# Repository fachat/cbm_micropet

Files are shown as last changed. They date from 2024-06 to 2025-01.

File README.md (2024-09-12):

# Micro-PET R3

Note: this is a part of a larger set of repositories, with [upet_family](https://github.com/fachat/upet_family) as the main repository.

This is a re-incarnation of the Commodore PET computer(s) from the later 1970s.

It is build on a PCB slightly larger than a Eurocard board and has only parts that can still be obtained new in 2024.
The current version is 3.0A

Picture of a MicroPET

Here is the [Overview video](https://youtu.be/COlfqcaY7rI)

Some more videos on the build process can be found here [YT 8-bit times](https://youtube.com/playlist?list=PLi1dzy7kw1iybjcUccgjCV4fhNH4IPWSx)

## Features

The board is built with a number of features:

- Commodore 3032 / 4032 / 8032 / 8296 with options menu to select at boot
  - Boot-menu to select different PET versions to run (BASIC 1, 2, 4)
  - 40 and 80 col character display
  - 8296 memory map emulation
  - IEEE488 interface (card edge and 24pin flat ribbon cable)
  - Tape connector (card edge, 5V only)
  - PET graphics keyboard, or alternatively a C64 keyboard
- Improved system design:
  - 512k video RAM, plus 512k fast RAM, accessible using banks on the W65816 CPU
  - boot from an SPI Flash ROM
  - up to 17.5 MHz mode (via configuration register)
  - Write protection for the PET ROMs once copied to RAM
  - lower 32k RAM mappable from all of the 512k fast RAM
  - Audio output using a DAC with DMA
- Improved Video output:
  - VGA colour video output
  - up to 96x72 characters on screen
  - hires modes up to a 768x576 resolution
  - 16 out of 64 colour palette, Colour-PET or C128 VDC-compatible, Sprites
  - Hires graphics mode (using a configuration register)
  - modifyable character set
  - multiple video pages mappable to $8000 video mem address

## Overview

The system architecture is actually rather simple, as you can see in the following graphics.

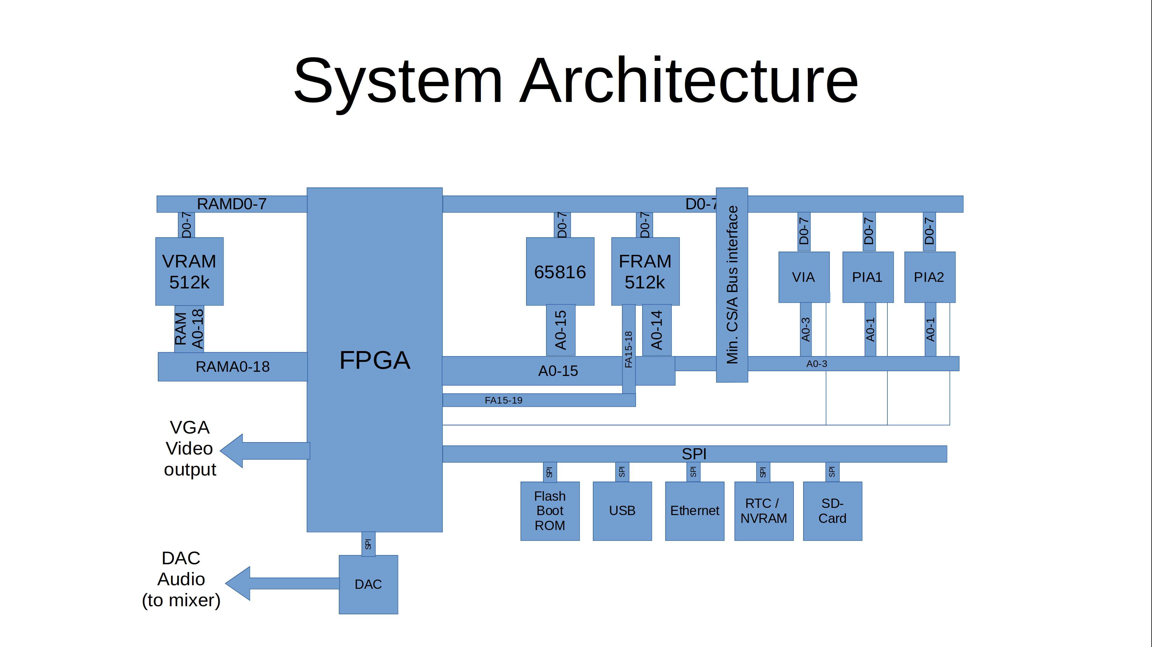
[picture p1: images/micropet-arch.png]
MicroPET System Architecture


The main functionality is "hidden" inside the FPGA. It does:

1. clock generation and management
2. memory mapping
3. video generation.
4. SPI interface and boot
5. DAC DMA

On the CPU side of the FPGA it is actually a rather almost normal 65816 computer, 
with the exception that the bank register (that catches and stores the address lines 
A16-23 from the CPU's data bus) is in the FPGA, and that there is no ROM. The ROM has been
replaced with some code in the FPGA that copies the initial program to the CPU accessible
RAM, taking it from the Flash Boot ROM via SPI. This actually simplifies the design,
as 

1. parallel ROMs are getting harder to come by and
2. they are typically not as fast as is needed, and
3. with the SPI boot they don't occupy valuable CPU address space.

The video generation is done using time-sharing access to the video RAM.
The VGA output is 768x576 at 60Hz. So there is a 28ns slot per pixel on the screen, 
with a pixel clock of 35MHz.

The system runs at 17.5MHz, so a byte of pixel output (i.e. eight pixels) has four
memory accesses to VRAM. Two of them are reserved for video access, one for fetching the
character data (e.g. at $08xxx in the PET), and the second one to fetch the "character ROM"
data, i.e. the pixel data for a character. This is also stored in VRAM, and is being loaded
there from the Flash Boot ROM by the initial boot loader.

The FPGA reads the character data, stores it to fetch the character pixel data, and streams
that out using its internal video shift register.

For more detailled descriptions of the features and how to use them, pls see the 
[FPGA repository](https://github.com/fachat/upet_fpga) that contains the code for the FPGA,
as described in the next section.

## Version History

- [Revision 2.1A](https://github.com/fachat/cbm_micropet/tree/r2.1a): the first one with boot-from-SPI, and card edge connectors for IEEE and tape.
- [Revision 1.1B](https://github.com/fachat/cbm_micropet/tree/r1.1b): the original one with parallel ROMs, and no SPI boot; also, no card edge connectors

## Building

Here are four subdirectories:

- [Board](Board/) that contains the board schematics and layout
- [Case](Case/) 3-D printed supports and keyboards to mount board in a C64c case

In addition, two other repositories are needed - they are separate as they are shared with other variants of the upet-family:

- [FPGA](https://github.com/fachat/upet_fpga) contains the VHDL code to program the FPGA logic chip used, and describes the configuration options - including the SPI usage, the DAC usage, and the Video features.
- [ROM](https://github.com/fachat/upet_roms) ROM contents to boot

### Board

To have the board built, you can use the gerbers that are stored in the zip file in the Board/production subdirectory.

To populate the board, there is an interactive bom (bill of materials) from KiCad, as well as the KiCad BOM CSV export in the [bom](Board/bom/) folder.
The parts I used are in the [Mouser BOM](Board/micropet_v3.0a-BOM.xlsx).

The BOM contains an Ethernet breakout board that is put into the connectors "above" the USB port. As an alternative you could use the 
[Wifi breakout board](https://github.com/fachat/upet_wifi). Note that at this time, this is not tested / programmed yet.

### FPGA

The FPGA is a Xilinx Spartan 6 programmable logic chip. It runs on 3.3V and it is programmed in VHDL.

To build the FPGA content, clone the [FPGA](https://github.com/fachat/upet_fpga) repository, and look for the ShellUPet.bin.
This needs to be programmed into the SPI flash chip containing the configration for the FPGA.

### ROM

To build the boot ROM image, clone the [ROM](https://github.com/fachat/upet_roms) repository, and build the spiimg70m file. This needs to be 
programmed into the SPI flash ROM containing the 65816 boot code.

The ROM image can be built using gcc, xa65, and make. Use your favourite EPROM programmer to burn it into the SPI Flash chip.

The ROM contains images of all required ROM images for BASIC 1, 2, and 4, and corresponding editor ROMs, including
some that have been extended with wedges.

The updated editor ROMs are from [Steve's Editor ROM project](http://www.6502.org/users/sjgray/projects/editrom/index.html) and can handle C64 keyboards, has a DOS wedge included, and resets into the Micro-PET boot menu.
For more details see the description in the ROM repository.

### Case

The [Case](Case/) subdirectory holds some supporting 3D models, to use an existing C64-II case for the Micro-PET. 

Also, it contains the models for custom key caps for a PET N-type keyboard, as is default for the Micro-PET. 
As keyboard PCB I suggest using Steve Gray's [PET keyboard replacements](http://cbmsteve.ca/mxkeyboards/index.html) using modern, MX-type key switches.

## Gallery (Still R2)

Picture of a MicroPET

Note: the published schematics and board has the extra wires fixed/included.

MicroPET with self-printed key caps

MicroPET running the 8296 burnin

MicroPET before adjusting a C64 case

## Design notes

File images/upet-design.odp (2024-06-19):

## System Architecture

A0-3

A0-1

A0-1

FA15-18

A0-15

D0-7

D0-7

D0-7

D0-7

SPI

SPI

SPI

SPI

SPI

SPI

D0-7

RAM
A0-18

D0-7

A0-14

Min. CS/A Bus interface

RAMD0-7

FPGA

D0-7

VRAM

512k

65816

FRAM

512k

VIA

PIA1

PIA2

RAMA0-18

VGA

Video

output

DAC

Audio

(to mixer)

A0-15

FA15-19

A0-3

SPI

Flash
Boot
ROM

USB

Ethernet

RTC /
NVRAM

SD-
Card

DAC

## Memory Map (boot)

ipl

ipl

CPU address space (lower 1M)

64k
bank0

Banks 0 … 7

Banks 8 … 15

64k
bank0

64k 8296

Ext. bank

Banks 2 … 7

64k video
bank

Banks 9 … 15

512k FRAM

Physical address space

The CPLD can only write (the IPL code from Flash) to VRAM, so the initial

Mapping maps VRAM to banks 0-7 of the CPU

512k VRAM

## Memory Map

CPU address space (lower 1M)

0-32k

32-
64k

Banks 1 … 15

Any of 16

32k blocks

In FRAM

4k
V

Bank 0, or

8296 mem expansion

In bank 1

Any of four 2k positions in video bank

8k
Chr

rom

8k
Chr

64k
bank0

64k 8296

Ext. bank

Banks 2 … 7

64k video
bank

Banks 9 … 15

512k FRAM

Physical address space

512k VRAM

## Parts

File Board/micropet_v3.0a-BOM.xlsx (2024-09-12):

Designator | Footprint | Quantity | Orig | Value | MOUSER | MPN | Alternate
BEEP1 | JP2 | 1 |  | PIEZOBEEPER | 253-AE2038E4WA | AE-2038E-4WA |  | (To be put on cable to JP2)
C1, C12, C13, C14, C15, C16, C17, C18, C19, C2, C20, C21, C22, C23, C24, C25, C27, C3, C31, C32, C33, C34, C35, C4, C41, C42, C43, C44, C45, C46, C47, C48, C53, C54, C55, C56, C57, C58, C59, C60, C61, C62, C63, C64, C67, C68, C69, C70, C71 | C0603 | 49 |  | 0.1u | 710-885012206020 | 885012206020
C10, C11 | C0603 | 2 |  | 1u | 710-885012206020 | 885012206020
C26 | E2,5-6 | 1 |  | 47u | 710-860010372004 | 860010372004
C28, C36, C37, C38 | E2,5-6 | 4 |  | 22u | 710-860010372002 | 860010372002
C29, C30, C39, C40 | C0603 | 4 |  | 18p | 80-C0603C180K4HACTU | C0603C180K4HACTU |  |  | 77-VJ0603A180JXQCBC | VJ0603A180JXQCW1BC
C49, C50, C51, C52 | C050-025X075 | 4 |  | 1u | 710-860020672005 | 860020672005
C5 | E5-8,5 | 1 |  | 47u | 710-860010372004 | 860010372004
C6 | E5-6 | 1 |  | 47u | 710-860010372004 | 860010372004
C65, C66 | C0805 | 2 |  | 22u | 187-CL21A226MPQNNNE | CL21A226MPQNNNE
C7, C8 | C0603 | 2 |  | 100n | 710-885012206020 | 885012206020
C9 | C0603 | 1 |  | 1.0u Cer | 710-885012206020 | 885012206020
D1, D5, D6, D8 | D-5 | 4 |  | 1N4148 | 78-1N4148 | 1N4148TR |  |  | 512-1N4148 | 1N4148
D10, D11, D2, D3, D4, D9 | DO35-7 | 6 |  | 1N4148DO35-7 | 78-1N4148 | 1N4148TR |  |  | 512-1N4148 | 1N4148
H1, H2, H3, H4, H5, H6, H7 | 3.2 |  | 7 | MOUNT-HOLE3.2
IC1, IC13 | SOP32 | 2 |  | RAMSOCK32TO512KSOP | 870-61C5128AS-25QLI | IS61C5128AS-25QLI
IC10, IC11 | PLCC44 | 2 |  | PIAPLCC | 955-W65C21N6TPLG-14 | W65C21N6TPLG-14
IC16 | SO24L | 1 |  | 74LVC8T245SO24 | 595-SN74LVC4245ADW | SN74LVC4245ADW |  |  | 595-74LVC8T245DWRG4 | SN74LVC8T245DWRG4
IC2 | SO20W | 1 |  | 74245DW | 595-SN74HCT245DWR | SN74HCT245DWR
IC3 | SO14 | 1 |  | 7400D | 595-SN74HCT00DR | SN74HCT00DR
IC4 | SO14 | 1 |  | 7486D | 771-74HCT86D-T | 74HCT86D,653
IC5 | DIL16 | 1 |  | 74145N | 595-SN74LS145N | SN74LS145N | 595-SN74LS145NE4 | SN74LS145NE4
IC6 | SO14 | 1 |  | 74125D | 595-SN74LVC125AD | SN74LVC125AD
IC7 | SO16 | 1 |  | 74138D | 771-74LVC138AD-T | 74LVC138AD,118
IC8 | TQFP32-5MM | 1 |  | MAX3421E | 700-MAX3421EEHJT | MAX3421EEHJ+T
IC9 | PLCC44 | 1 |  | VIAPLCC | 955-W65C22N6TPLG-14 | W65C22N6TPLG-14
 | PLCC44 Socket | 4 |  |  | 517-8444-11B1-RK-TP | 8444-11B1-RK-TP
 | DIL16 Socket | 1 |  |  | 571-1-2199298-4 | 1-2199298-4
 | DIL20 Socket | 2 |  |  | 571-1-2199298-6 | 1-2199298-6
 | DIL08 Socket | 2 |  |  | 571-1-2199298-2 | 1-2199298-2
J1 | DCJ0202 | 1 |  | DCJ0202 | 806-KLDX-0202-A | KLDX-0202-A
JP1, JP10, JP6 | JP2 |  | 3 | JP2E
JP2, JP3, JP4, JP5, JP8, JP9 | JP1 |  | 6 | JP1E
JP7 | JP4 |  | 1 | JP4E
P6 | JP6 |  | 1 | CBMTAPE
P1 | C64KEYB |  | 1 | C64KEYB
P7 | C64KEYB |  | 1 | PETKEYBD
U$11 | JP6 |  | 1 | PETSKEY_EXTRA
U$8 | PinHeader_1x07_P2.54mm_Vertical |  | 1 | JP7
 |  | 3 |  | pin strip straight 20 pin | 649-1012937892001BLF | 10129378-920001BLF
JS1 | RENJS6 | 1 |  | RENOSCXLH | 972-XLH536070000000I | XLH536070.000000I
U$7 | FLAT10BOX | 1 |  | XILINXPROG | 710-61201021621 | 61201021621
LED1 | LED3MM | 1 |  | LED3MM | 696-SSL-LX305F4GD | SSL-LX305F4GD
P2 | FLAT24 | 1 |  | IEEE488FLATCABLE | 710-61202421621 | 61202421621
P3 | FLAT24 | 1 |  | PETUSERPORT | 710-61202421621 | 61202421621
Q1 | MICRO3 | 1 |  | IRLML5203 | 942-IRLML5203TRPBF | IRLML5203TRPBF
Q2 | TC26H | 1 |  | 32kHz | 710-830002995B | 830002995B
Q3 | HC49_S | 1 |  | 12MHz | 549-CYS6Q31C-12MHZ | CYS6Q31C-12.000MHZ
R20, R21, R6 | 0207_2V | 3 |  | 10 | 603-MF0207FTE26-10R | MF0207FTE26-10R
R1, R2, R4 | 0204_7 | 3 |  | 33 | 660-MF1/4LCT52R330J | MF1/4LCT52R330J
R7, R8 | 0204V | 2 |  | 68 | 660-MF1/4LCT52R680G | MF1/4LCT52R680G
R18, R31 | 0204V | 2 |  | 100 | 603-MFR-12FTF52-100R | MFR-12FTF52-100R
R29 | 0207_2V | 1 |  | 330 | 603-MFR-12FTF52-330R | MFR-12FTF52-330R
R17, R22 | 0207_2V | 2 |  | 390 | 756-MFR3-390RFC | MFR3-390RFC |  |  | 603-MFR-25FBF52-390R | MFR-25FBF52-390R
R13, R14, R15 | 0204V | 3 |  | 470 | 708-RNF14FTD470R | RNF14FTD470R
R30, R32 | 0204V | 2 |  | 680 | 603-MFR-12FTF52-680R | MFR-12FTF52-680R
R26, R27, R28 | 0204V | 3 |  | 1k | 603-MFR-12FTF52-1K | MFR-12FTF52-1K
R5 | 0204_5 | 1 |  | 2k2 | 603-MFR-12FTF52-2K2 | MFR-12FTF52-2K2
R3 | 0207_2V | 1 |  | 2k4 | 71-CCF072K40JKE36 | CCF072K40JKE36
R23 | 0204_5 | 1 |  | 3k3 | 603-MFR-12FTF52-3K3 | MFR-12FTF52-3K3
R25 | 0207_2V | 1 |  | 4k7 | 603-MFR-12FTF52-3K3 | MFR-12FTF52-4K7
R10, R11, R24, R9 | 0207_2V | 4 |  | 10k | 756-MFR3-10KFC | MFR3-10KFC
R16 | 0207_2V | 1 |  | 100k | 756-MFR3-100KFC | MFR3-100KFC
RN1 | RN-9 | 1 |  | 10k | 652-4609X-1LF-10K | 4609X-101-103LF
RN2, RN4 | RN-9 | 2 |  | 2k4 | 652-4609X-1LF-2.2K | 4609X-101-222LF
RN3, RN5 | RN-9 | 2 |  | 5k1 | 652-4609X-101-512LF | 4609X-101-512LF
S1 | B3F-31XX | 1 |  | 31-XX | 653-B3F-3122 | B3F-3122
SN1 | SOIC8 | 1 |  | MCP48X2 | 579-MCP4802-E/SN | MCP4802-E/SN
U$1 | PLCC44 | 1 |  | W65C816SPLCC | 955-W65C816S6PLG-14 | W65C816S6PLG-14
U$12 | GRAVITECH-SDCARD | 1 |  | SD-CARD-GRAVI | 992-MICROSD-ADP | MICROSD-ADP
 |  | 1 |  | Socket | 200-BCS108LSTE | BCS-108-L-S-TE
U$13 | MSOP10 | 1 |  | MCP79510 | 579-MCP79510-I/MS | MCP79510-I/MS
U$14, U$4 | DIL08 | 2 |  | SPIFLASH | 804-25VF080B5CPAE | SST25VF080B-50-4C-PAE |  |  | Other 4M/8M SPI Flash chips may work, mileage may vary (this Spartan6 req. > 2.7M)
U$16 | PSOP-8-FIXED | 1 |  | AP2132BB | 621-AP2132BMP1.2TRG1 | AP2132BMP-1.2TRG1
U$2 | TQFP144 | 1 |  | XC6SLX9-TQG144 | 217-XC6SLX9-2TQG144C | XC6SLX9-2TQG144C
U$3 | TO92 | 1 |  | DS1813 | 700-DS1818-10T&R | DS1818-10+T&R
U$5, U$6 | DIL20 | 2 |  | 74LS641 | 595-SN74LS641-1N | SN74LS641-1N
U$9 | ETHOLIENC | 1 |  | ETHOLIENC | 909-ENC28J60-H | ENC28J60-H
 |  | 2 |  |  | 200-BCS105LSTE | BCS-105-L-S-TE
U1 | SOT-223-3_TabPin2 | 1 |  | AMS1117-3.3 | 637-LDI1117-3.3H | LDI1117-3.3H
U2 | SOT-23-5 | 1 |  | 74LVC1G04 | 595-SN74LVC1G04DBVR | SN74LVC1G04DBVR
USB1 | USB-A-H | 1 |  | USB-A-H | 710-614004190021 | 614004190021
X1 | 1503_09 | 1 |  | 1503_09 | 490-SJ1-3513N | SJ1-3513N |  |  | Jack connectors according to JISC 6560, 3.5 mm
X2 | HDR15RA | 1 |  | D-SUB15-HDR15RA | 523-7HDE15SD1CH4FVGA | L77HDE15SD1CH4FVGA
CN3 | MA156_6-2_KEYED |  | 1 | PORT_CASSETTE_EDGE
CN4 | MA156_12-2_IEEE |  | 1 | PORT_IEEE_EDGE

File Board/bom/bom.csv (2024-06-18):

Designator | Footprint | Quantity | Value | LCSC Part #
BEEP1 | JP2 | 1 | PIEZOBEEPER
C1, C12, C13, C14, C15, C16, C17, C18, C19, C2, C20, C21, C22, C23, C24, C25, C27, C3, C31, C32, C33, C34, C35, C4, C41, C42, C43, C44, C45, C46, C47, C48, C53, C54, C55, C56, C57, C58, C59, C60, C61, C62, C63, C64, C67, C68, C69, C70, C71 | C0603 | 49 | 0.1u
C10, C11 | C0603 | 2 | 1u
C26 | E2,5-6 | 1 | 47u
C28, C36, C37, C38 | E2,5-6 | 4 | 22u
C29, C30, C39, C40 | C0603 | 4 | 18p
C49, C50, C51, C52 | C050-025X075 | 4 | 1u
C5 | E5-8,5 | 1 | 47u
C6 | E5-6 | 1 | 47u
C65, C66 | C0805 | 2 | 22u
C7, C8 | C0603 | 2 | 100n
C9 | C0603 | 1 | 1.0u Cer
CN3 | MA156_6-2_KEYED | 1 | PORT_CASSETTE_EDGE
CN4 | MA156_12-2_IEEE | 1 | PORT_IEEE_EDGE
D1, D5, D6, D8 | D-5 | 4 | 1N4148
D10, D11, D2, D3, D4, D9 | DO35-7 | 6 | 1N4148DO35-7
H1, H2, H3, H4, H5, H6, H7 | 3,2 | 7 | MOUNT-HOLE3.2
IC1, IC13 | SOP32 | 2 | RAMSOCK32TO512KSOP
IC10, IC11 | PLCC44 | 2 | PIAPLCC
IC16 | SO24L | 1 | 74LVC8T245SO24
IC2 | SO20W | 1 | 74245DW
IC3 | SO14 | 1 | 7400D
IC4 | SO14 | 1 | 7486D
IC5 | DIL16 | 1 | 74145N
IC6 | SO14 | 1 | 74125D
IC7 | SO16 | 1 | 74138D
IC8 | TQFP32-5MM | 1 | MAX3421E
IC9 | PLCC44 | 1 | VIAPLCC
J1 | DCJ0202 | 1 | DCJ0202
JP1, JP10, JP6 | JP2 | 3 | JP2E
JP2, JP3, JP4, JP5, JP8, JP9 | JP1 | 6 | JP1E
JP7 | JP4 | 1 | JP4E
JS1 | RENJS6 | 1 | RENOSCXLH
LED1 | LED3MM | 1 | LED3MM
P1 | C64KEYB | 1 | C64KEYB
P2 | FLAT24 | 1 | IEEE488FLATCABLE
P3 | FLAT24 | 1 | PETUSERPORT
P6 | JP6 | 1 | CBMTAPE
P7 | C64KEYB | 1 | PETKEYBD
Q1 | MICRO3 | 1 | IRLML5203
Q2 | TC26H | 1 | 32kHz
Q3 | HC49_S | 1 | 12MHz
R1, R2, R4 | 0204_7 | 3 | 33
R10, R11, R24, R9 | 0207_2V | 4 | 10k
R13, R14, R15 | 0204V | 3 | 470
R16 | 0207_2V | 1 | 100k
R17, R22 | 0207_2V | 2 | 390
R18, R31 | 0204V | 2 | 100
R20, R21, R6 | 0207_2V | 3 | 10
R23 | 0204_5 | 1 | 3k3
R25 | 0207_2V | 1 | 4k7
R26, R27, R28 | 0204V | 3 | 1k
R29 | 0207_2V | 1 | 330
R3 | 0207_2V | 1 | 2k4
R30, R32 | 0204V | 2 | 680
R5 | 0204_5 | 1 | 2k2
R7, R8 | 0204V | 2 | 68
RN1 | RN-9 | 1 | 10k
RN2, RN4 | RN-9 | 2 | 2k4
RN3, RN5 | RN-9 | 2 | 5k1
S1 | B3F-31XX | 1 | 31-XX
SN1 | SOIC8 | 1 | MCP48X2
U$1 | PLCC44 | 1 | W65C816SPLCC
U$11 | JP6 | 1 | PETSKEY_EXTRA
U$12 | GRAVITECH-SDCARD | 1 | SD-CARD-GRAVI
U$13 | MSOP10 | 1 | MCP79510
U$14, U$4 | DIL08 | 2 | SPIFLASH
U$16 | PSOP-8-FIXED | 1 | AP2132BB
U$2 | TQFP144 | 1 | XC6SLX9-TQG144
U$3 | TO92 | 1 | DS1813
U$5, U$6 | DIL20 | 2 | 74LS641
U$7 | FLAT10BOX | 1 | XILINXPROG
U$8 | PinHeader_1x07_P2.54mm_Vertical | 1 | JP7
U$9 | ETHOLIENC | 1 | ETHOLIENC
U1 | SOT-223-3_TabPin2 | 1 | AMS1117-3.3
U2 | SOT-23-5 | 1 | 74LVC1G04
USB1 | USB-A-H | 1 | USB-A-H
X1 | 1503_09 | 1 | 1503_09
X2 | HDR15RA | 1 | D-SUB15-HDR15RA

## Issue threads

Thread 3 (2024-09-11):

bom link on title page is broken, and no XLS bom in repo (eom)

fachat, 2024-09-11:

Closed 2024-09-12.

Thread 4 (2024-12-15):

Tape connector pinout wrong

fachat, 2024-12-15:
The tape connector pinout is wrong.

5V and GND are ok, but the other signals are mixed up.

DO NOT USE the TAPE connector other than for power supply!

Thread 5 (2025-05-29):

Error in BOM

tutigit, 2025-05-29:
In the schematic, RN2 and RN4 are 2.4K resistor networks.

The BOM, however, contains an error:

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

I've now equipped it with 2.2K (and will do so again in the Ultimate Pet), and it's not that different. Maybe you should correct it anyway.

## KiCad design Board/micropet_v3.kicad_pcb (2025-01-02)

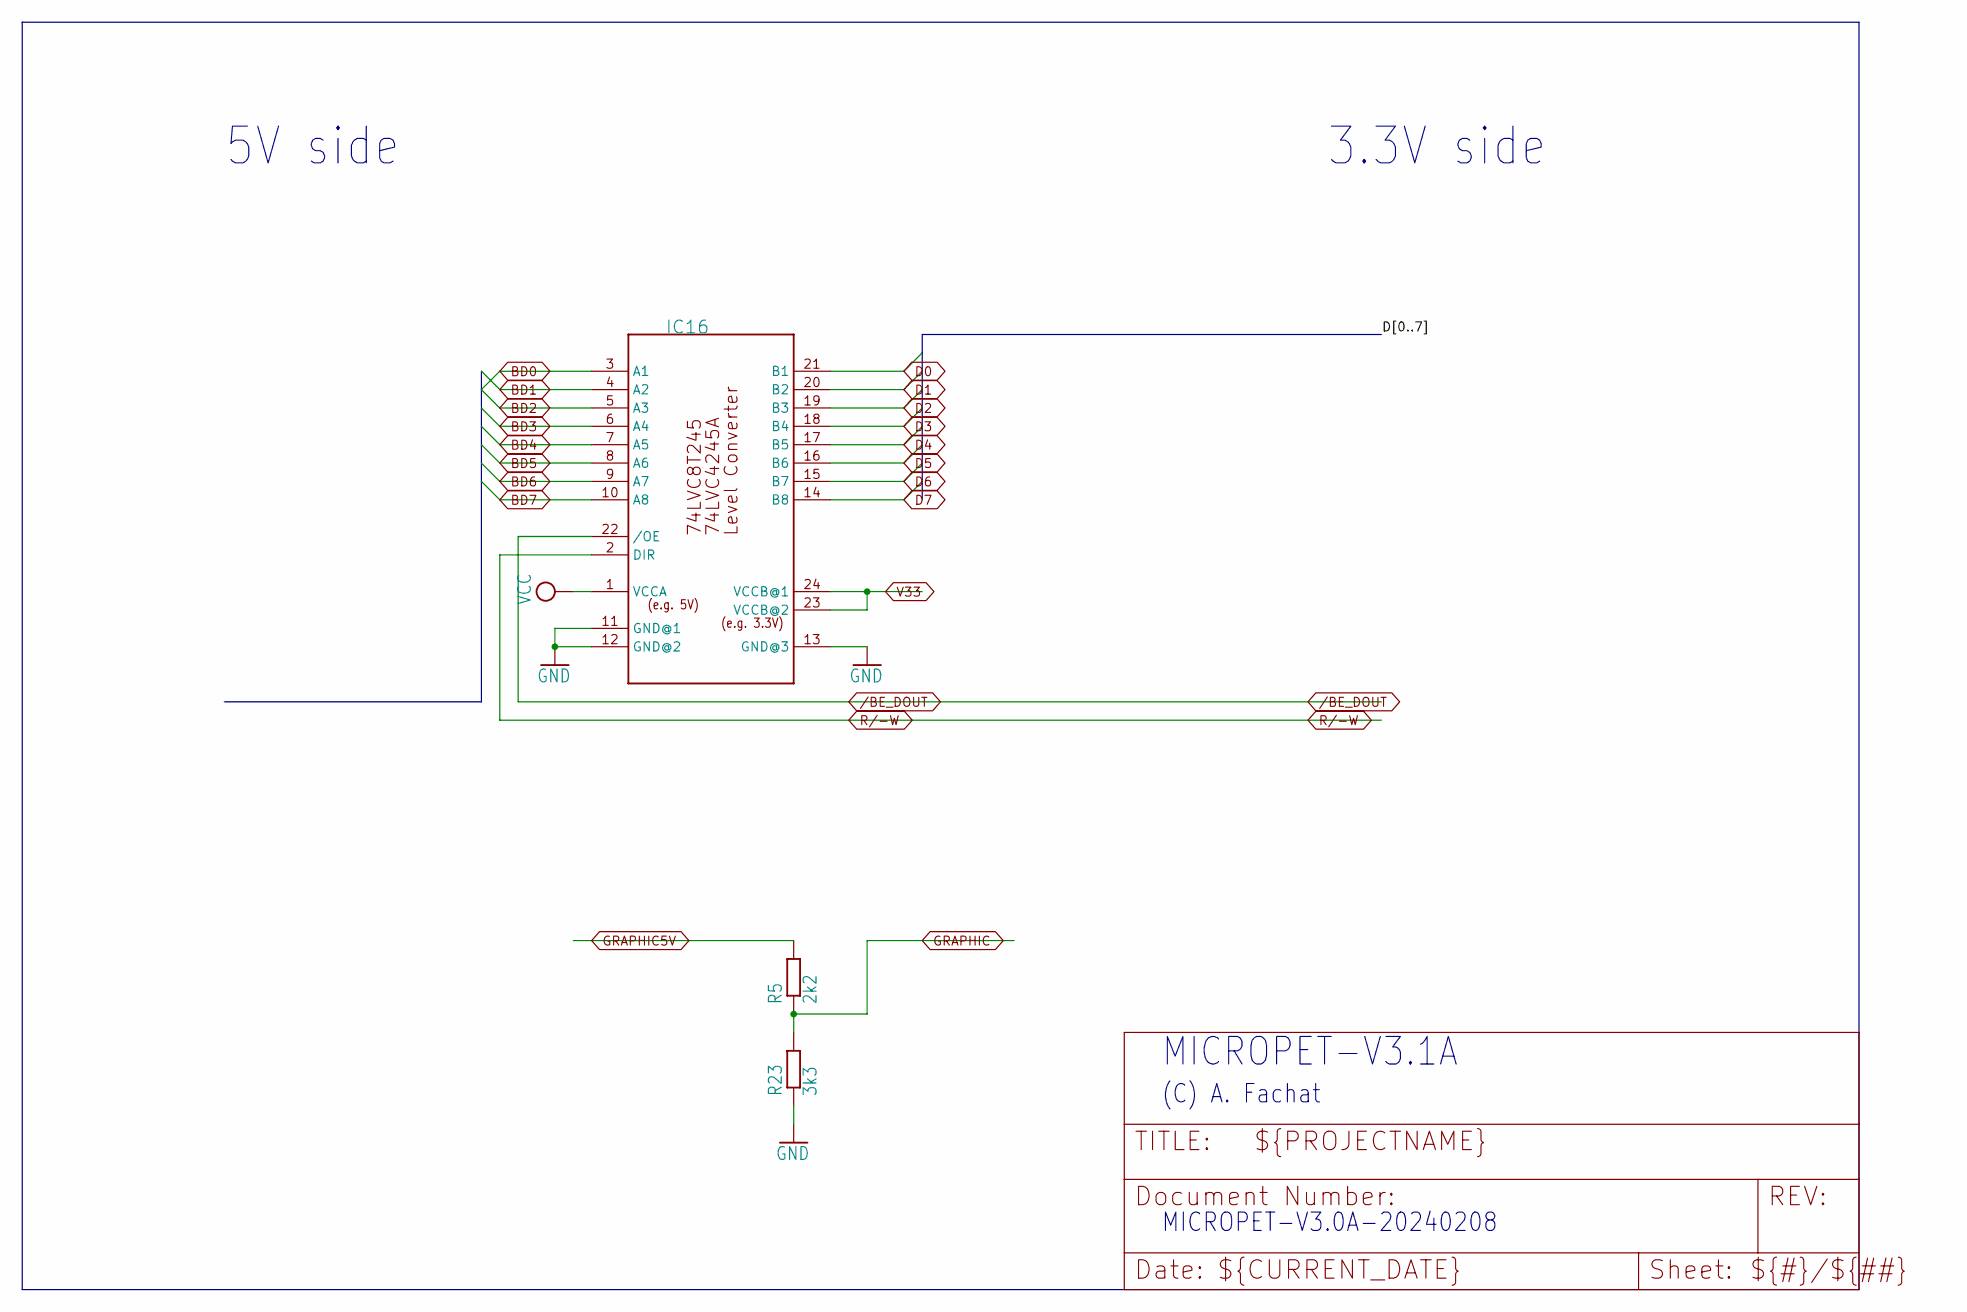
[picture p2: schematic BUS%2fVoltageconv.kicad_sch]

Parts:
IC16: 74LVC8T245SO24; SO24L
R5: 2k2; 0204_5
R23: 3k3; 0204_5

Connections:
BD0: IC16.3 (A1); also elsewhere on the board
BD1: IC16.4 (A2); also elsewhere on the board
BD2: IC16.5 (A3); also elsewhere on the board
BD3: IC16.6 (A4); also elsewhere on the board
BD4: IC16.7 (A5); also elsewhere on the board
BD5: IC16.8 (A6); also elsewhere on the board
BD6: IC16.9 (A7); also elsewhere on the board
BD7: IC16.10 (A8); also elsewhere on the board
D0: IC16.21 (B1); also elsewhere on the board
D1: IC16.20 (B2); also elsewhere on the board
D2: IC16.19 (B3); also elsewhere on the board
D3: IC16.18 (B4); also elsewhere on the board
D4: IC16.17 (B5); also elsewhere on the board
D5: IC16.16 (B6); also elsewhere on the board
D6: IC16.15 (B7); also elsewhere on the board
D7: IC16.14 (B8); also elsewhere on the board
GND: IC16.11 (GND@1), IC16.12 (GND@2), IC16.13 (GND@3), R23.1; also elsewhere on the board
GRAPHIC: R5.1, R23.2; also elsewhere on the board
GRAPHIC5V: R5.2; also elsewhere on the board
V33: IC16.23 (VCCB@2), IC16.24 (VCCB@1); also elsewhere on the board
VCC: IC16.1 (VCCA); also elsewhere on the board
/BE_DOUT: IC16.22 (/OE); also elsewhere on the board

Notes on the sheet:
3.3V side
MICROPET-V3.1A
(C) A. Fachat
5V side
MICROPET-V3.0A-20240208

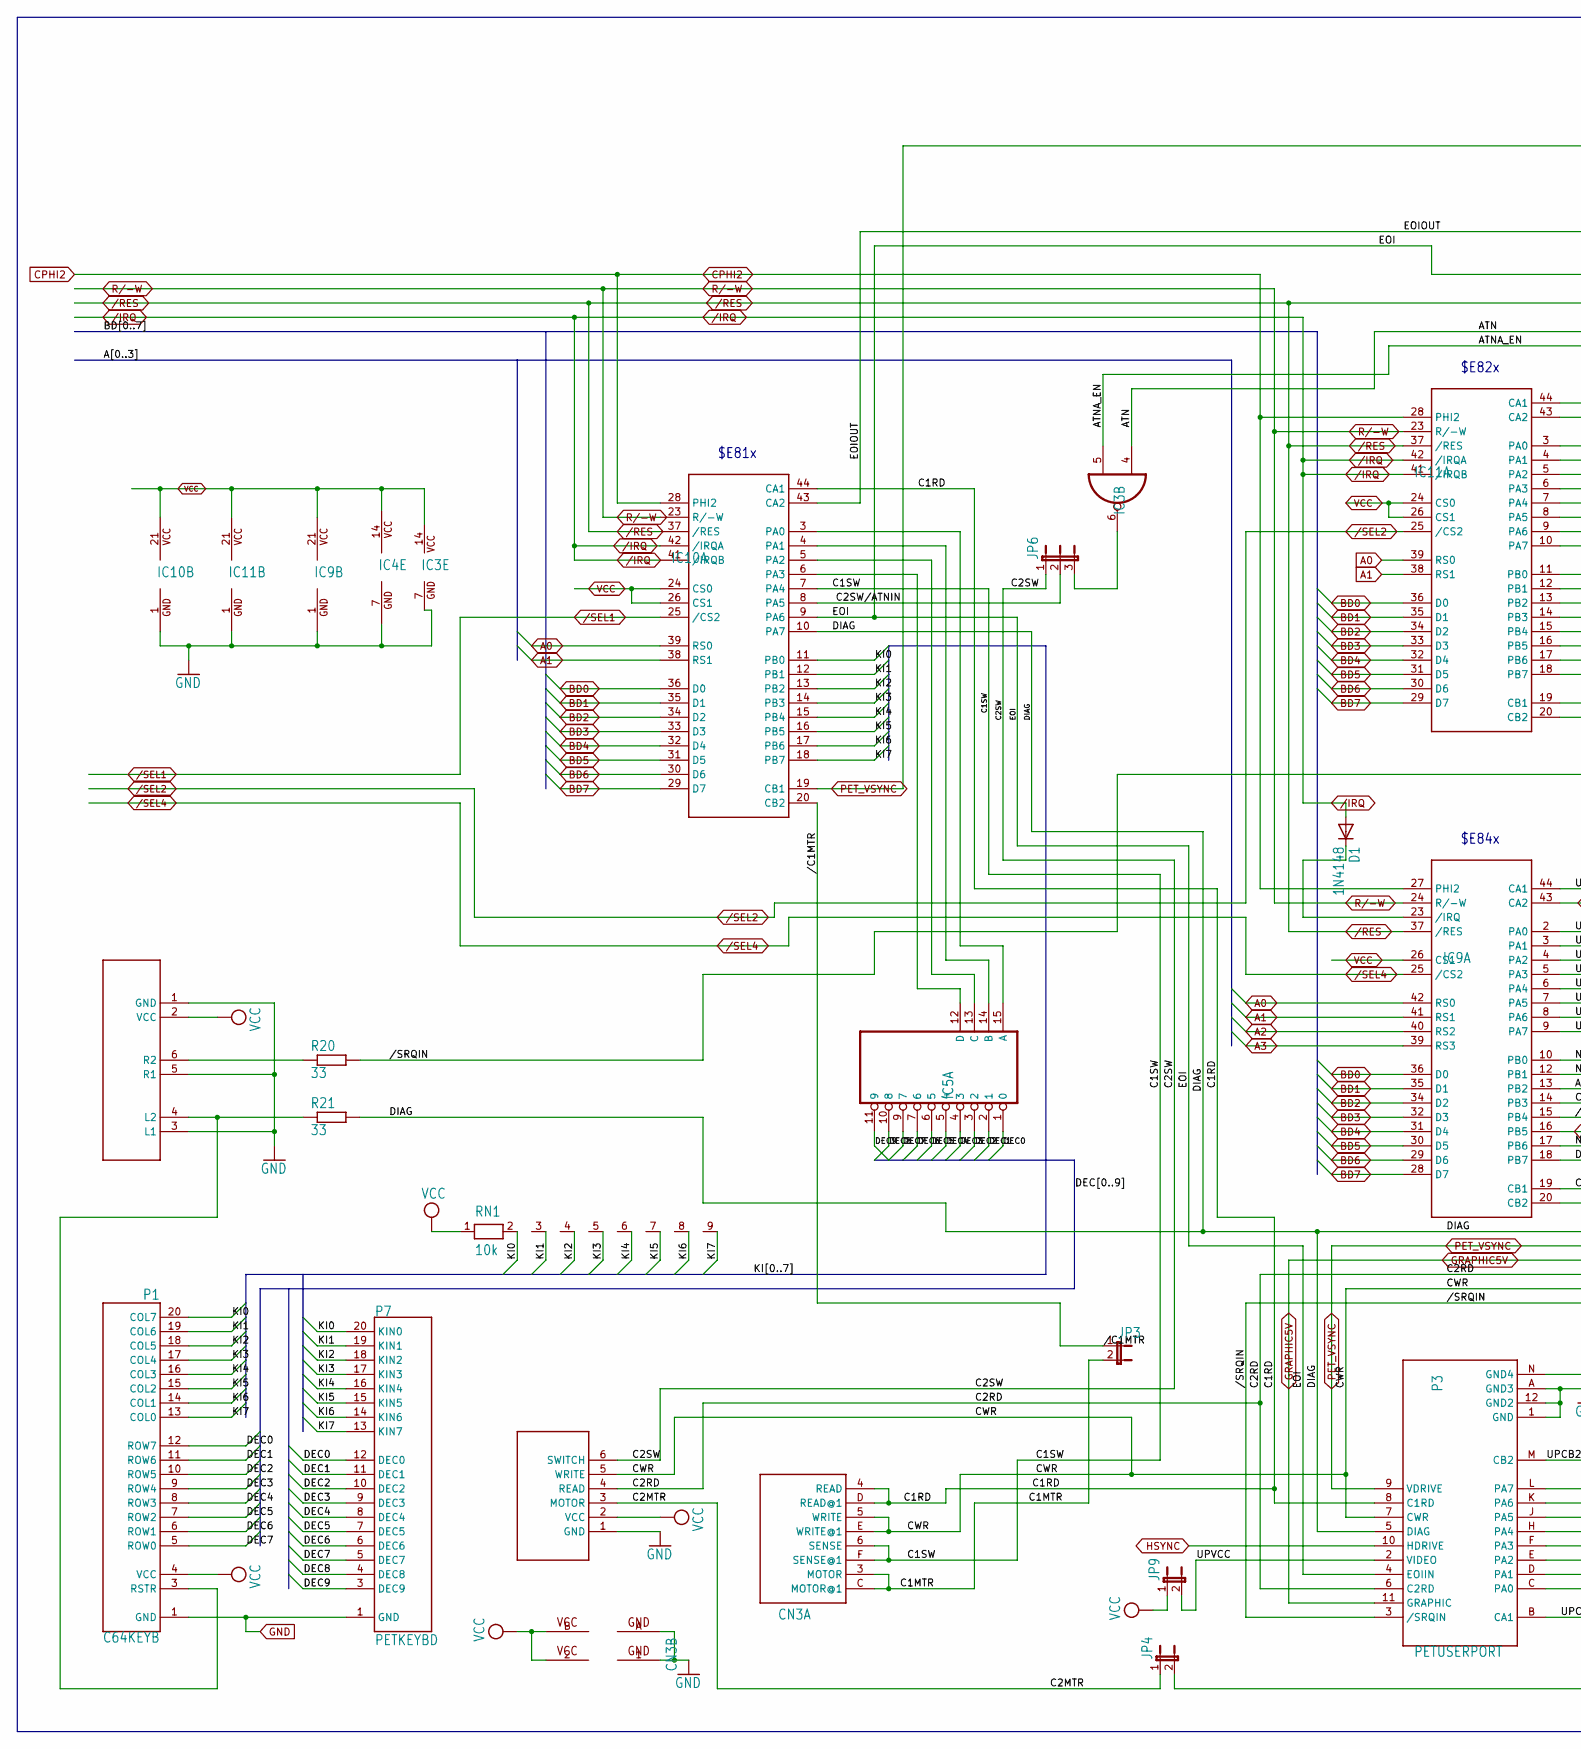
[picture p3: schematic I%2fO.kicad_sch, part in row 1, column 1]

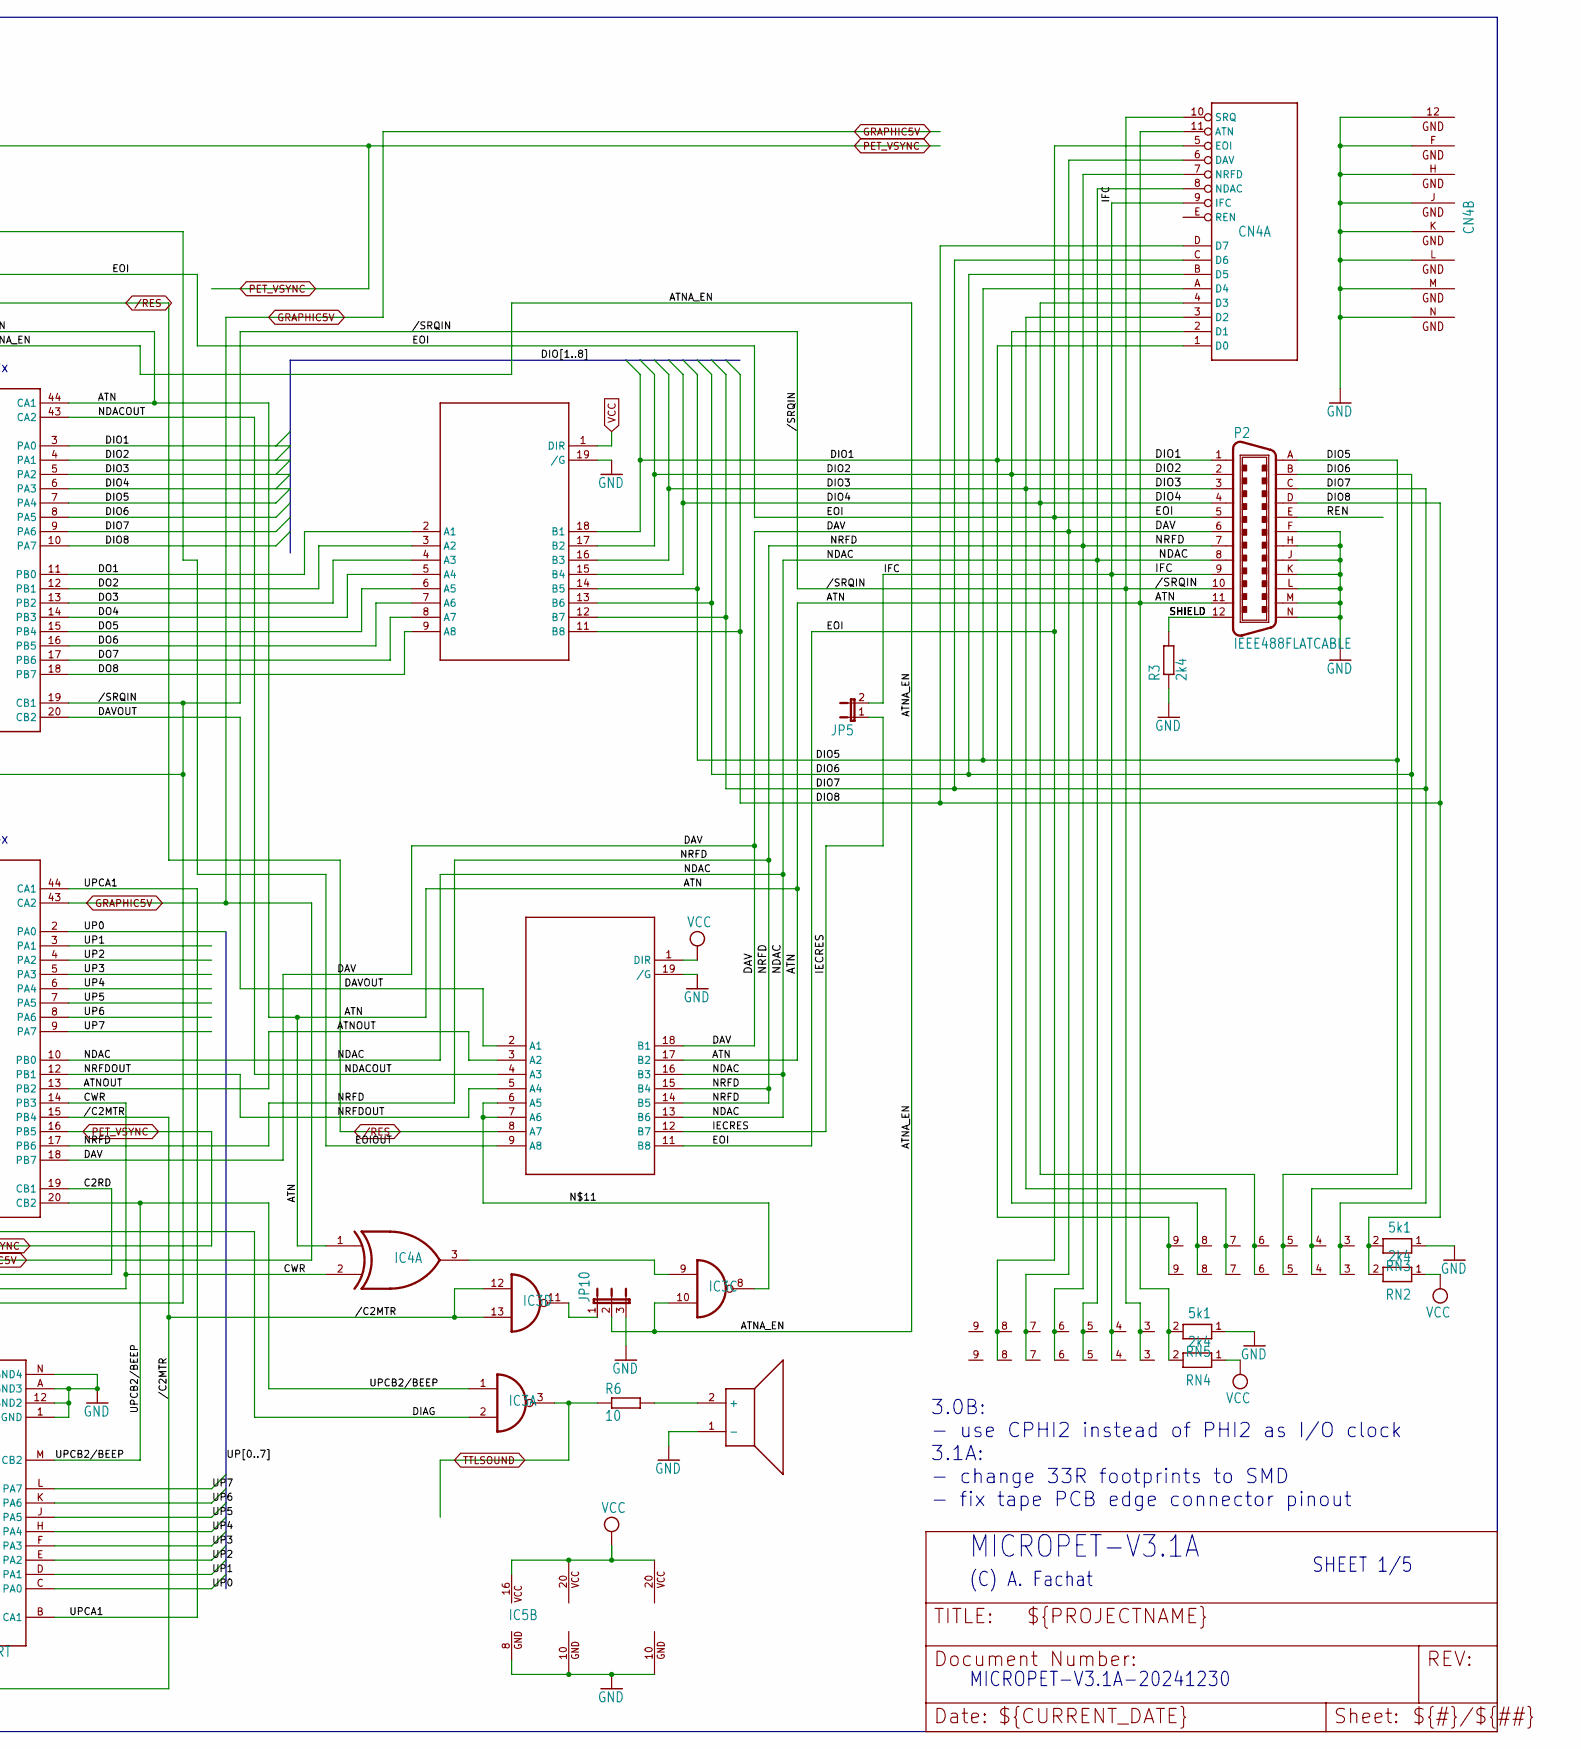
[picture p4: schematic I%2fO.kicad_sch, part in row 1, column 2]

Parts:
BEEP1: PIEZOBEEPER; JP2
CN3: PORT_CASSETTE_EDGE; MA156_6-2_KEYED
CN4: PORT_IEEE_EDGE; MA156_12-2_IEEE
D1: 1N4148; D-5
IC3: 7400D; SO14
IC4: 7486D; SO14
IC5: 74145N; DIL16
IC9: VIAPLCC; PLCC44
IC10, IC11: PIAPLCC; PLCC44
JP3, JP4, JP5, JP9: JP1E; JP1
JP6, JP10: JP2E; JP2
P1: C64KEYB
P2: IEEE488FLATCABLE; FLAT24
P3: PETUSERPORT; FLAT24
P6: CBMTAPE; JP6
P7: PETKEYBD; C64KEYB
R3: 2k4; 0207_2V
R6: 10; 0207_2V
R20, R21: 33; R_0805_2012Metric_Pad1.20x1.40mm_HandSolder
RN1: 10k; RN-9
RN2, RN4: 2k4; RN-9
RN3, RN5: 5k1; RN-9
U$5, U$6: 74LS641; DIL20
U$11: PETSKEY_EXTRA; JP6

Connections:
/I/O/ATN: CN4.11 (ATN), IC3.4 (I0), IC4.1 (I0), IC11.44 (CA1), P2.11, RN4.2, RN5.2, U$6.17 (B2)
/I/O/ATNA_EN: IC3.5 (I1), IC3.10 (I1), JP10.2
/I/O/ATNOUT: IC9.13 (PB2), U$6.3 (A2)
/I/O/C1MTR: CN3.3 (MOTOR), CN3.C (MOTOR@1), JP3.2
/I/O/C1RD: CN3.4 (READ), CN3.D (READ@1), IC10.44 (CA1), P3.8 (C1RD)
/I/O/C1SW: CN3.6 (SENSE), CN3.F (SENSE@1), IC10.7 (PA4)
/I/O/C2MTR: JP4.1, P6.3 (MOTOR)
/I/O/C2RD: IC9.19 (CB1), P3.6 (C2RD), P6.4 (READ)
/I/O/C2SW: JP6.1, P6.6 (SWITCH)
/I/O/C2SW/ATNIN: IC10.8 (PA5), JP6.2
/I/O/CWR: CN3.5 (WRITE), CN3.E (WRITE@1), IC4.2 (I1), IC9.14 (PB3), P3.7 (CWR), P6.5 (WRITE)
/I/O/DAV: CN4.6 (DAV), IC9.18 (PB7), P2.6, RN4.7, RN5.7, U$6.18 (B1)
/I/O/DAVOUT: IC11.20 (CB2), U$6.2 (A1)
/I/O/DEC0: IC5.1 (0), P1.12 (ROW7), P7.12 (DEC0)
/I/O/DEC1: IC5.2 (1), P1.11 (ROW6), P7.11 (DEC1)
/I/O/DEC2: IC5.3 (2), P1.10 (ROW5), P7.10 (DEC2)
/I/O/DEC3: IC5.4 (3), P1.9 (ROW4), P7.9 (DEC3)
/I/O/DEC4: IC5.5 (4), P1.8 (ROW3), P7.8 (DEC4)
/I/O/DEC5: IC5.6 (5), P1.7 (ROW2), P7.7 (DEC5)
/I/O/DEC6: IC5.7 (6), P1.6 (ROW1), P7.6 (DEC6)
/I/O/DEC7: IC5.9 (7), P1.5 (ROW0), P7.5 (DEC7)
/I/O/DEC8: IC5.10 (8), P7.4 (DEC8)
/I/O/DEC9: IC5.11 (9), P7.3 (DEC9)
/I/O/DIAG: IC3.2 (I1), IC10.10 (PA7), P3.5 (DIAG), R21.2
/I/O/DIO1: CN4.1 (D0), IC11.3 (PA0), P2.1, RN2.9, RN3.9, U$5.18 (B1)
/I/O/DIO2: CN4.2 (D1), IC11.4 (PA1), P2.2, RN2.8, RN3.8, U$5.17 (B2)
/I/O/DIO3: CN4.3 (D2), IC11.5 (PA2), P2.3, RN2.7, RN3.7, U$5.16 (B3)
/I/O/DIO4: CN4.4 (D3), IC11.6 (PA3), P2.4, RN2.6, RN3.6, U$5.15 (B4)
/I/O/DIO5: CN4.A (D4), IC11.7 (PA4), P2.A (13), RN2.5, RN3.5, U$5.14 (B5)
/I/O/DIO6: CN4.B (D5), IC11.8 (PA5), P2.B (14), RN2.4, RN3.4, U$5.13 (B6)
/I/O/DIO7: CN4.C (D6), IC11.9 (PA6), P2.C (15), RN2.3, RN3.3, U$5.12 (B7)
/I/O/DIO8: CN4.D (D7), IC11.10 (PA7), P2.D (16), RN2.2, RN3.2, U$5.11 (B8)
/I/O/DO1: IC11.11 (PB0), U$5.2 (A1)
/I/O/DO2: IC11.12 (PB1), U$5.3 (A2)
/I/O/DO3: IC11.13 (PB2), U$5.4 (A3)
/I/O/DO4: IC11.14 (PB3), U$5.5 (A4)
/I/O/DO5: IC11.15 (PB4), U$5.6 (A5)
/I/O/DO6: IC11.16 (PB5), U$5.7 (A6)
/I/O/DO7: IC11.17 (PB6), U$5.8 (A7)
/I/O/DO8: IC11.18 (PB7), U$5.9 (A8)
/I/O/EOI: CN4.5 (EOI), IC10.9 (PA6), P2.5, P3.4 (EOIIN), RN4.8, RN5.8, U$6.11 (B8)
/I/O/EOIOUT: IC10.43 (CA2), U$6.9 (A8)
/I/O/IECRES: JP5.1, U$6.12 (B7)
/I/O/IFC: CN4.9 (IFC), JP5.2, P2.9, RN4.4, RN5.4
/I/O/KI0: IC10.11 (PB0), P1.20 (COL7), P7.20 (KIN0), RN1.2
/I/O/KI1: IC10.12 (PB1), P1.19 (COL6), P7.19 (KIN1), RN1.3
/I/O/KI2: IC10.13 (PB2), P1.18 (COL5), P7.18 (KIN2), RN1.4
/I/O/KI3: IC10.14 (PB3), P1.17 (COL4), P7.17 (KIN3), RN1.5
/I/O/KI4: IC10.15 (PB4), P1.16 (COL3), P7.16 (KIN4), RN1.6
/I/O/KI5: IC10.16 (PB5), P1.15 (COL2), P7.15 (KIN5), RN1.7
/I/O/KI6: IC10.17 (PB6), P1.14 (COL1), P7.14 (KIN6), RN1.8
/I/O/KI7: IC10.18 (PB7), P1.13 (COL0), P7.13 (KIN7), RN1.9
/I/O/N$11: IC3.8 (O), U$6.6 (A5), U$6.7 (A6)
/I/O/NDAC: CN4.8 (NDAC), IC9.10 (PB0), P2.8, RN4.5, RN5.5, U$6.13 (B6), U$6.16 (B3)
/I/O/NDACOUT: IC11.43 (CA2), U$6.4 (A3)
/I/O/NRFD: CN4.7 (NRFD), IC9.17 (PB6), P2.7, RN4.6, RN5.6, U$6.14 (B5), U$6.15 (B4)
/I/O/NRFDOUT: IC9.12 (PB1), U$6.5 (A4)
/I/O/REN: P2.E (17)
/I/O/SHIELD: P2.12, R3.2
/I/O/UP0: IC9.2 (PA0), P3.C (PA0)
/I/O/UP1: IC9.3 (PA1), P3.D (PA1)
/I/O/UP2: IC9.4 (PA2), P3.E (PA2)
/I/O/UP3: IC9.5 (PA3), P3.F (PA3)
/I/O/UP4: IC9.6 (PA4), P3.H (PA4)
/I/O/UP5: IC9.7 (PA5), P3.J (PA5)
/I/O/UP6: IC9.8 (PA6), P3.K (PA6)
/I/O/UP7: IC9.9 (PA7), P3.L (PA7)
/I/O/UPCA1: IC9.44 (CA1), P3.B (CA1)
/I/O/UPCB2/BEEP: IC3.1 (I0), IC9.20 (CB2), P3.M (CB2)
/I/O/UPVCC: JP9.2, P3.2 (VIDEO)
/I/O//C1MTR: IC10.20 (CB2), JP3.1
/I/O//C2MTR: IC3.12 (I0), IC3.13 (I1), IC9.15 (PB4), JP4.2
/I/O//SRQIN: CN4.10 (SRQ), IC11.19 (CB1), P2.10, P3.3 (/SRQIN), R20.2, RN4.3, RN5.3
A0: IC9.42 (RS0), IC10.39 (RS0), IC11.39 (RS0); also elsewhere on the board
A1: IC9.41 (RS1), IC10.38 (RS1), IC11.38 (RS1); also elsewhere on the board
A2: IC9.40 (RS2); also elsewhere on the board
A3: IC9.39 (RS3); also elsewhere on the board
BD0: IC9.36 (D0), IC10.36 (D0), IC11.36 (D0); also elsewhere on the board
BD1: IC9.35 (D1), IC10.35 (D1), IC11.35 (D1); also elsewhere on the board
BD2: IC9.34 (D2), IC10.34 (D2), IC11.34 (D2); also elsewhere on the board
BD3: IC9.32 (D3), IC10.33 (D3), IC11.33 (D3); also elsewhere on the board
BD4: IC9.31 (D4), IC10.32 (D4), IC11.32 (D4); also elsewhere on the board
BD5: IC9.30 (D5), IC10.31 (D5), IC11.31 (D5); also elsewhere on the board
BD6: IC9.29 (D6), IC10.30 (D6), IC11.30 (D6); also elsewhere on the board
BD7: IC9.28 (D7), IC10.29 (D7), IC11.29 (D7); also elsewhere on the board
CPHI2: IC9.27 (PHI2), IC10.28 (PHI2), IC11.28 (PHI2); also elsewhere on the board
GND: BEEP1.1 (-), CN3.1 (GND), CN3.A (GND@1), CN4.12 (GND), CN4.F (GND@1), CN4.H (GND@2), CN4.J (GND@3), CN4.K (GND@4), CN4.L (GND@5), CN4.M (GND@6), CN4.N (GND@7), IC3.7 (GND), IC4.7 (GND), IC5.8 (GND), IC9.1 (GND), IC10.1 (GND), IC11.1 (GND), JP10.3, P1.1 (GND), P2.F (18), P2.H (19), P2.J (20), P2.K (21), P2.L (22), P2.M (23), P2.N (24), P3.1 (GND), P3.12 (GND2), P3.A (GND3), P3.N (GND4), P6.1 (GND), P7.1 (GND), R3.1, RN3.1, RN5.1, U$5.10 (GND), U$5.19 (/G), U$6.10 (GND), U$6.19 (/G), U$11.1 (GND), U$11.3 (L1), U$11.5 (R1); also elsewhere on the board
GRAPHIC5V: IC9.43 (CA2), P3.11 (GRAPHIC); also elsewhere on the board
HSYNC: P3.10 (HDRIVE); also elsewhere on the board
unnamed: BEEP1.2 (+), R6.2
unnamed: IC3.6 (O), JP6.3
unnamed: IC3.9 (I0), IC4.3 (O)
unnamed: IC3.11 (O), JP10.1
unnamed: D1.C, IC9.23 (/IRQ)
unnamed: IC5.15 (A), IC10.3 (PA0)
unnamed: IC5.14 (B), IC10.4 (PA1)
unnamed: IC5.13 (C), IC10.5 (PA2)
unnamed: IC5.12 (D), IC10.6 (PA3)
unnamed: P1.3 (RSTR), R21.1, U$11.4 (L2)
unnamed: R20.1, U$11.6 (R2)
PET_VSYNC: IC9.16 (PB5), IC10.19 (CB1), P3.9 (VDRIVE); also elsewhere on the board
TTLSOUND: IC3.3 (O), R6.1; also elsewhere on the board
VCC: CN3.2 (VCC), CN3.B (VCC@1), IC3.14 (VCC), IC4.14 (VCC), IC5.16 (VCC), IC9.21 (VCC), IC9.26 (CS1), IC10.21 (VCC), IC10.24 (CS0), IC10.26 (CS1), IC11.21 (VCC), IC11.24 (CS0), IC11.26 (CS1), JP9.1, P1.4 (VCC), P6.2 (VCC), RN1.1, RN2.1, RN4.1, U$5.1 (DIR), U$5.20 (VCC), U$6.1 (DIR), U$6.20 (VCC), U$11.2 (VCC); also elsewhere on the board
/IRQ: D1.A, IC10.41 (/IRQB), IC10.42 (/IRQA), IC11.41 (/IRQB), IC11.42 (/IRQA); also elsewhere on the board
/SEL1: IC10.25 (/CS2); also elsewhere on the board
/SEL2: IC11.25 (/CS2); also elsewhere on the board
/SEL4: IC9.25 (/CS2); also elsewhere on the board

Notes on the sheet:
$E84x
$E82x
MICROPET-V3.1A
MICROPET-V3.1A-20241230
(C) A. Fachat
$E81x
3.0B: - use CPHI2 instead of PHI2 as I/O clock 3.1A: - change 33R footprints to SMD - fix tape PCB edge connector pinout
SHEET 1/5

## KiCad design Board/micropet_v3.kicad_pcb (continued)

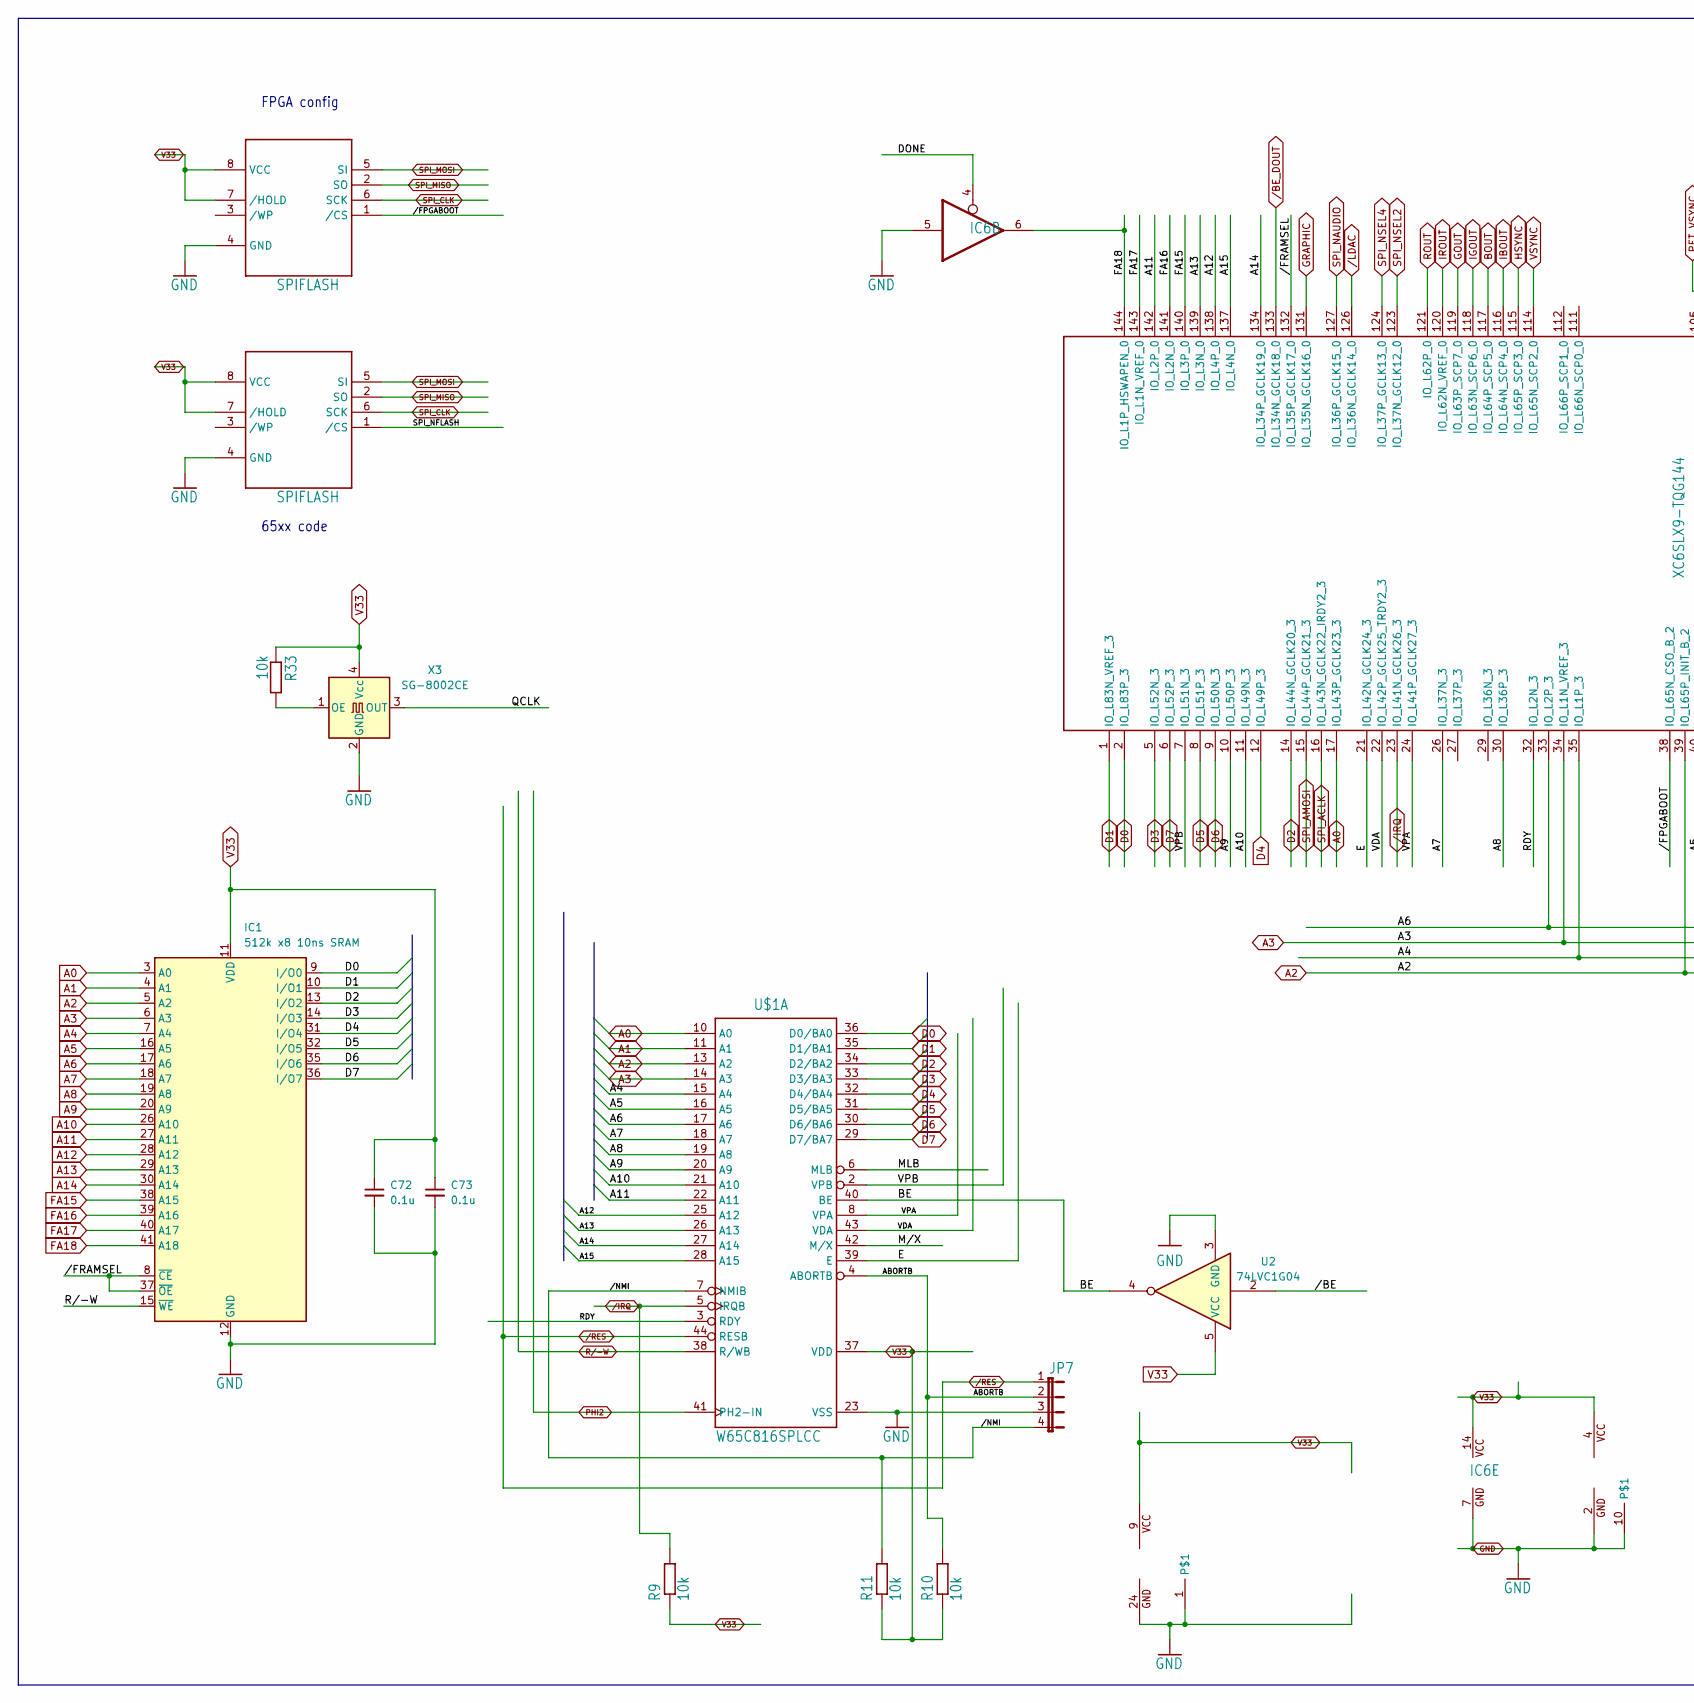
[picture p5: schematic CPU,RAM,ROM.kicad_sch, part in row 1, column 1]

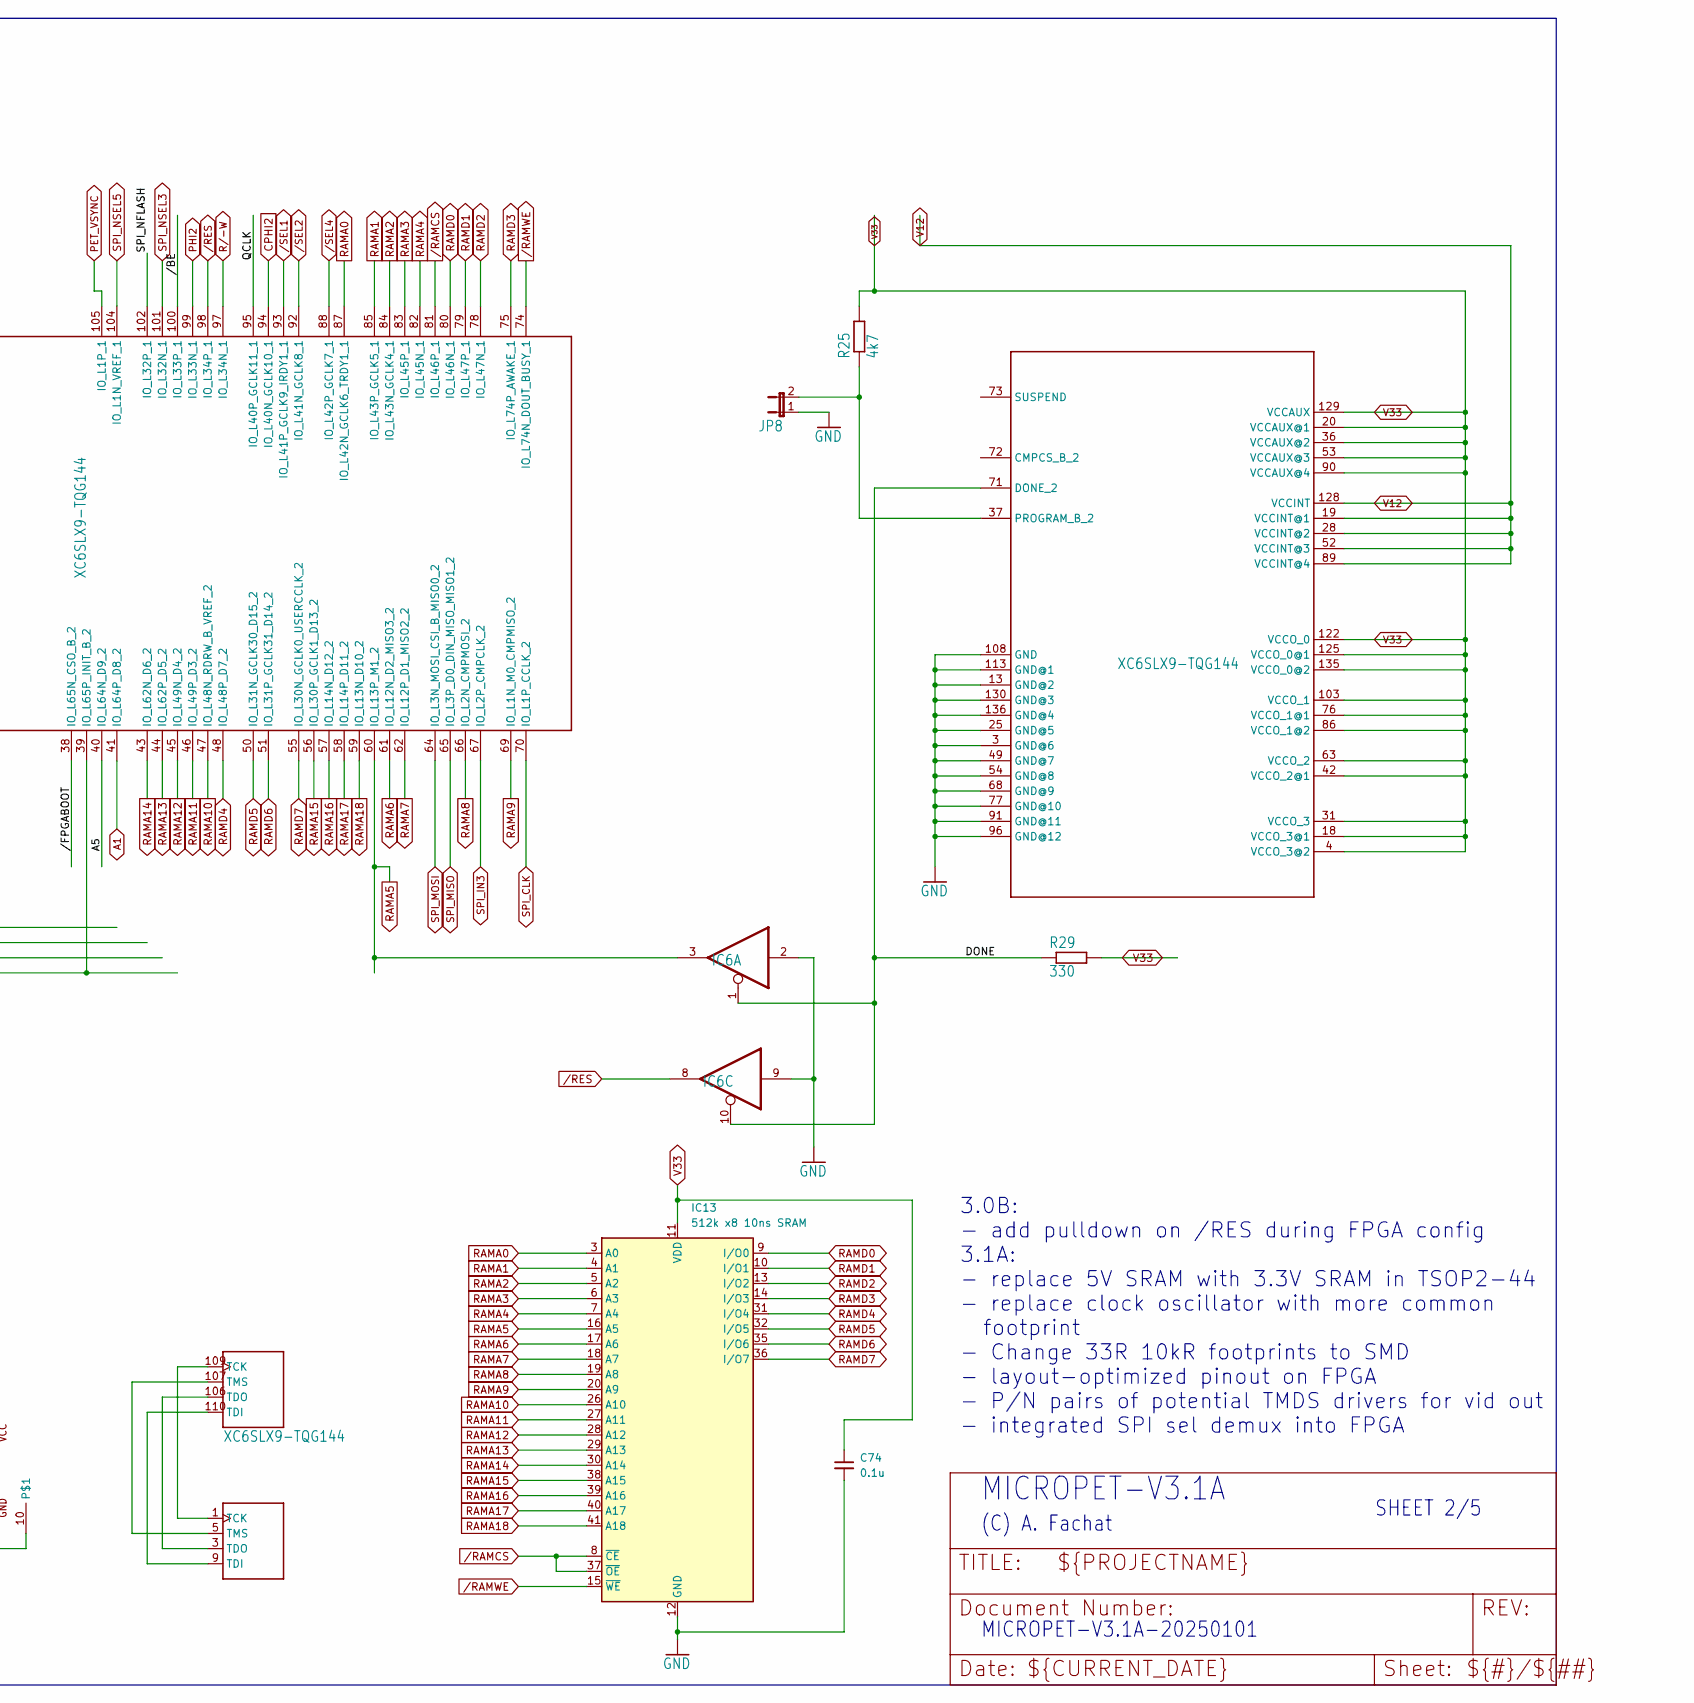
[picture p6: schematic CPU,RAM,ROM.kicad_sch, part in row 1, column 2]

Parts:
C72, C73, C74: 0.1u; C_0603_1608Metric
IC1, IC13: 512k x8 10ns SRAM; TSOP-II-44_10.16x18.41mm_P0.8mm
IC6: 74125D; SO14
JP7: JP4E; JP4
JP8: JP1E; JP1
R9, R10, R11, R33: 10k; R_0805_2012Metric_Pad1.20x1.40mm_HandSolder
R25: 4k7; 0207_2V
R29: 330; 0207_2V
U2: 74LVC1G04; SOT-23-5
U$1: W65C816SPLCC; PLCC44
U$2: XC6SLX9-TQG144; TQFP144
U$4, U$14: SPIFLASH; DIL08
U$7: XILINXPROG; FLAT10BOX
X3: SG-8002CE; Oscillator_SMD_SeikoEpson_SG8002CE-4Pin_3.2x2.5mm

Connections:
/CPU,RAM,ROM/A15: U$1.28 (A15), U$2.137 (IO_L4N_0)
/CPU,RAM,ROM/ABORTB: JP7.2, R10.2, U$1.4 (ABORTB)
/CPU,RAM,ROM/BE: U2.4, U$1.40 (BE)
/CPU,RAM,ROM/DONE: IC6.1 (OE), IC6.4 (OE), IC6.10 (OE), R29.1, U$2.71 (DONE_2)
/CPU,RAM,ROM/E: U$1.39 (E), U$2.21 (IO_L42N_GCLK24_3)
/CPU,RAM,ROM/MLB: U$1.6 (MLB)
/CPU,RAM,ROM/M/X: U$1.42 (M/X)
/CPU,RAM,ROM/QCLK: U$2.95 (IO_L40P_GCLK11_1), X3.3 (OUT)
/CPU,RAM,ROM/RDY: U$1.3 (RDY), U$2.32 (IO_L2N_3)
/CPU,RAM,ROM/SPI_NFLASH: U$2.102 (IO_L32P_1), U$4.1 (/CS)
/CPU,RAM,ROM/VDA: U$1.43 (VDA), U$2.22 (IO_L42P_GCLK25_TRDY2_3)
/CPU,RAM,ROM/VPA: U$1.8 (VPA), U$2.24 (IO_L41P_GCLK27_3)
/CPU,RAM,ROM/VPB: U$1.2 (VPB), U$2.7 (IO_L51N_3)
/CPU,RAM,ROM//BE: U2.2, U$2.100 (IO_L33P_1)
/CPU,RAM,ROM//NMI: JP7.4, R11.2, U$1.7 (NMIB)
A0: IC1.3 (A0), U$1.10 (A0), U$2.17 (IO_L43P_GCLK23_3); also elsewhere on the board
A1: IC1.4 (A1), U$1.11 (A1), U$2.41 (IO_L64P_D8_2); also elsewhere on the board
A2: IC1.5 (A2), U$1.13 (A2), U$2.39 (IO_L65P_INIT_B_2); also elsewhere on the board
A3: IC1.6 (A3), U$1.14 (A3), U$2.34 (IO_L1N_VREF_3); also elsewhere on the board
A4: IC1.7 (A4), U$1.15 (A4), U$2.35 (IO_L1P_3)
A5: IC1.16 (A5), U$1.16 (A5), U$2.40 (IO_L64N_D9_2)
A6: IC1.17 (A6), U$1.17 (A6), U$2.33 (IO_L2P_3)
A7: IC1.18 (A7), U$1.18 (A7), U$2.26 (IO_L37N_3)
A8: IC1.19 (A8), U$1.19 (A8), U$2.30 (IO_L36P_3)
A9: IC1.20 (A9), U$1.20 (A9), U$2.10 (IO_L50P_3)
A10: IC1.26 (A10), U$1.21 (A10), U$2.11 (IO_L49N_3)
A11: IC1.27 (A11), U$1.22 (A11), U$2.142 (IO_L2P_0)
A12: IC1.28 (A12), U$1.25 (A12), U$2.138 (IO_L4P_0)
A13: IC1.29 (A13), U$1.26 (A13), U$2.139 (IO_L3N_0)
A14: IC1.30 (A14), U$1.27 (A14), U$2.134 (IO_L34P_GCLK19_0)
BOUT: U$2.117 (IO_L64P_SCP5_0); also elsewhere on the board
CPHI2: U$2.94 (IO_L40N_GCLK10_1); also elsewhere on the board
D0: IC1.9 (I/O0), U$1.36 (D0/BA0), U$2.2 (IO_L83P_3); also elsewhere on the board
D1: IC1.10 (I/O1), U$1.35 (D1/BA1), U$2.1 (IO_L83N_VREF_3); also elsewhere on the board
D2: IC1.13 (I/O2), U$1.34 (D2/BA2), U$2.14 (IO_L44N_GCLK20_3); also elsewhere on the board
D3: IC1.14 (I/O3), U$1.33 (D3/BA3), U$2.5 (IO_L52N_3); also elsewhere on the board
D4: IC1.31 (I/O4), U$1.32 (D4/BA4), U$2.12 (IO_L49P_3); also elsewhere on the board
D5: IC1.32 (I/O5), U$1.31 (D5/BA5), U$2.8 (IO_L51P_3); also elsewhere on the board
D6: IC1.35 (I/O6), U$1.30 (D6/BA6), U$2.9 (IO_L50N_3); also elsewhere on the board
D7: IC1.36 (I/O7), U$1.29 (D7/BA7), U$2.6 (IO_L52P_3); also elsewhere on the board
FA15: IC1.38 (A15), U$2.140 (IO_L3P_0)
FA16: IC1.39 (A16), U$2.141 (IO_L2N_0)
FA17: IC1.40 (A17), U$2.143 (IO_L1N_VREF_0)
FA18: IC1.41 (A18), IC6.6 (O), U$2.144 (IO_L1P_HSWAPEN_0)
GND: C72.2, C73.2, C74.2, IC1.12 (GND), IC1.34 (GND), IC6.2 (I), IC6.5 (I), IC6.7 (GND), IC6.9 (I), IC13.12 (GND), IC13.34 (GND), JP7.3, JP8.1, U2.3 (GND), U$1.1, U$1.23 (VSS), U$1.24 (GND), U$2.3 (GND@6), U$2.13 (GND@2), U$2.25 (GND@5), U$2.49 (GND@7), U$2.54 (GND@8), U$2.68 (GND@9), U$2.77 (GND@10), U$2.91 (GND@11), U$2.96 (GND@12), U$2.108 (GND), U$2.113 (GND@1), U$2.130 (GND@3), U$2.136 (GND@4), U$4.4 (GND), U$7.2 (GND), U$7.10, U$14.4 (GND), X3.2 (GND); also elsewhere on the board
GOUT: U$2.119 (IO_L63P_SCP7_0); also elsewhere on the board
GRAPHIC: U$2.131 (IO_L35N_GCLK16_0); also elsewhere on the board
HSYNC: U$2.115 (IO_L65P_SCP3_0); also elsewhere on the board
IBOUT: U$2.116 (IO_L64N_SCP4_0); also elsewhere on the board
IGOUT: U$2.118 (IO_L63N_SCP6_0); also elsewhere on the board
IROUT: U$2.120 (IO_L62N_VREF_0); also elsewhere on the board
unnamed: JP8.2, R25.1, U$2.37 (PROGRAM_B_2)
unnamed: U$2.109 (TCK), U$7.1 (TCK)
unnamed: U$2.110 (TDI), U$7.9 (TDI)
unnamed: U$2.106 (TDO), U$7.3 (TDO)
unnamed: U$2.107 (TMS), U$7.5 (TMS)
unnamed: R33.2, X3.1 (OE)
PET_VSYNC: U$2.105 (IO_L1P_1); also elsewhere on the board
PHI2: U$1.41 (PH2-IN), U$2.99 (IO_L33N_1)
RAMA0: IC13.3 (A0), U$2.87 (IO_L42N_GCLK6_TRDY1_1)
RAMA1: IC13.4 (A1), U$2.85 (IO_L43P_GCLK5_1)
RAMA2: IC13.5 (A2), U$2.84 (IO_L43N_GCLK4_1)
RAMA3: IC13.6 (A3), U$2.83 (IO_L45P_1)
RAMA4: IC13.7 (A4), U$2.82 (IO_L45N_1)
RAMA5: IC6.3 (O), IC13.16 (A5), U$2.60 (IO_L13P_M1_2)
RAMA6: IC13.17 (A6), U$2.61 (IO_L12N_D2_MISO3_2)
RAMA7: IC13.18 (A7), U$2.62 (IO_L12P_D1_MISO2_2)
RAMA8: IC13.19 (A8), U$2.66 (IO_L2N_CMPMOSI_2)
RAMA9: IC13.20 (A9), U$2.69 (IO_L1N_M0_CMPMISO_2)
RAMA10: IC13.26 (A10), U$2.47 (IO_L48N_RDRW_B_VREF_2)
RAMA11: IC13.27 (A11), U$2.46 (IO_L49P_D3_2)
RAMA12: IC13.28 (A12), U$2.45 (IO_L49N_D4_2)
RAMA13: IC13.29 (A13), U$2.44 (IO_L62P_D5_2)
RAMA14: IC13.30 (A14), U$2.43 (IO_L62N_D6_2)
RAMA15: IC13.38 (A15), U$2.56 (IO_L30P_GCLK1_D13_2)
RAMA16: IC13.39 (A16), U$2.57 (IO_L14N_D12_2)
RAMA17: IC13.40 (A17), U$2.58 (IO_L14P_D11_2)
RAMA18: IC13.41 (A18), U$2.59 (IO_L13N_D10_2)
RAMD0: IC13.9 (I/O0), U$2.80 (IO_L46N_1)
RAMD1: IC13.10 (I/O1), U$2.79 (IO_L47P_1)
RAMD2: IC13.13 (I/O2), U$2.78 (IO_L47N_1)
RAMD3: IC13.14 (I/O3), U$2.75 (IO_L74P_AWAKE_1)
RAMD4: IC13.31 (I/O4), U$2.48 (IO_L48P_D7_2)
RAMD5: IC13.32 (I/O5), U$2.50 (IO_L31N_GCLK30_D15_2)
RAMD6: IC13.35 (I/O6), U$2.51 (IO_L31P_GCLK31_D14_2)
RAMD7: IC13.36 (I/O7), U$2.55 (IO_L30N_GCLK0_USERCCLK_2)
ROUT: U$2.121 (IO_L62P_0); also elsewhere on the board
SPI_ACLK: U$2.16 (IO_L43N_GCLK22_IRDY2_3); also elsewhere on the board
SPI_AMOSI: U$2.15 (IO_L44P_GCLK21_3); also elsewhere on the board
SPI_CLK: U$2.70 (IO_L1P_CCLK_2), U$4.6 (SCK), U$14.6 (SCK); also elsewhere on the board
SPI_IN3: U$2.67 (IO_L2P_CMPCLK_2); also elsewhere on the board
SPI_MISO: U$2.65 (IO_L3P_D0_DIN_MISO_MISO1_2), U$4.2 (SO), U$14.2 (SO); also elsewhere on the board
SPI_MOSI: U$2.64 (IO_L3N_MOSI_CSI_B_MISO0_2), U$4.5 (SI), U$14.5 (SI); also elsewhere on the board
SPI_NAUDIO: U$2.127 (IO_L36P_GCLK15_0); also elsewhere on the board
SPI_NSEL2: U$2.123 (IO_L37N_GCLK12_0); also elsewhere on the board
SPI_NSEL3: U$2.101 (IO_L32N_1); also elsewhere on the board
SPI_NSEL4: U$2.124 (IO_L37P_GCLK13_0); also elsewhere on the board
SPI_NSEL5: U$2.104 (IO_L1N_VREF_1); also elsewhere on the board
V12: U$2.19 (VCCINT@1), U$2.28 (VCCINT@2), U$2.52 (VCCINT@3), U$2.89 (VCCINT@4), U$2.128 (VCCINT); also elsewhere on the board
V33: C72.1, C73.1, C74.1, IC1.11 (VDD), IC1.33 (VDD), IC6.14 (VCC), IC13.11 (VDD), IC13.33 (VDD), R9.1, R10.1, R11.1, R25.2, R29.2, R33.1, U2.5 (VCC), U$1.9 (VCC), U$1.37 (VDD), U$2.4 (VCCO_3@2), U$2.18 (VCCO_3@1), U$2.20 (VCCAUX@1), U$2.31 (VCCO_3), U$2.36 (VCCAUX@2), U$2.42 (VCCO_2@1), U$2.53 (VCCAUX@3), U$2.63 (VCCO_2), U$2.76 (VCCO_1@1), U$2.86 (VCCO_1@2), U$2.90 (VCCAUX@4), U$2.103 (VCCO_1), U$2.122 (VCCO_0), U$2.125 (VCCO_0@1), U$2.129 (VCCAUX), U$2.135 (VCCO_0@2), U$4.7 (/HOLD), U$4.8 (VCC), U$7.4 (VCC), U$14.7 (/HOLD), U$14.8 (VCC), X3.4 (Vcc); also elsewhere on the board
VSYNC: U$2.114 (IO_L65N_SCP2_0); also elsewhere on the board
/BE_DOUT: U$2.133 (IO_L34N_GCLK18_0); also elsewhere on the board
/IRQ: R9.2, U$1.5 (IRQB), U$2.23 (IO_L41N_GCLK26_3); also elsewhere on the board
/LDAC: U$2.126 (IO_L36N_GCLK14_0); also elsewhere on the board
/RAMCS: IC13.8 (~CE), IC13.37 (~OE), U$2.81 (IO_L46P_1)
/RAMWE: IC13.15 (~WE), U$2.74 (IO_L74N_DOUT_BUSY_1)
/SEL1: U$2.93 (IO_L41P_GCLK9_IRDY1_1); also elsewhere on the board
/SEL2: U$2.92 (IO_L41N_GCLK8_1); also elsewhere on the board
/SEL4: U$2.88 (IO_L42P_GCLK7_1); also elsewhere on the board

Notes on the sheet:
(C) A. Fachat
SHEET 2/5
MICROPET-V3.1A
MICROPET-V3.1A-20250101
FPGA config
3.0B: - add pulldown on /RES during FPGA config 3.1A: - replace 5V SRAM with 3.3V SRAM in TSOP2-44 - replace clock oscillator with more common footprint - Change 33R 10kR footprints to SMD - layout-optimized pinout on FPGA - P/N pairs of potential TMDS drivers for vid out - integrated SPI sel demux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
65xx code

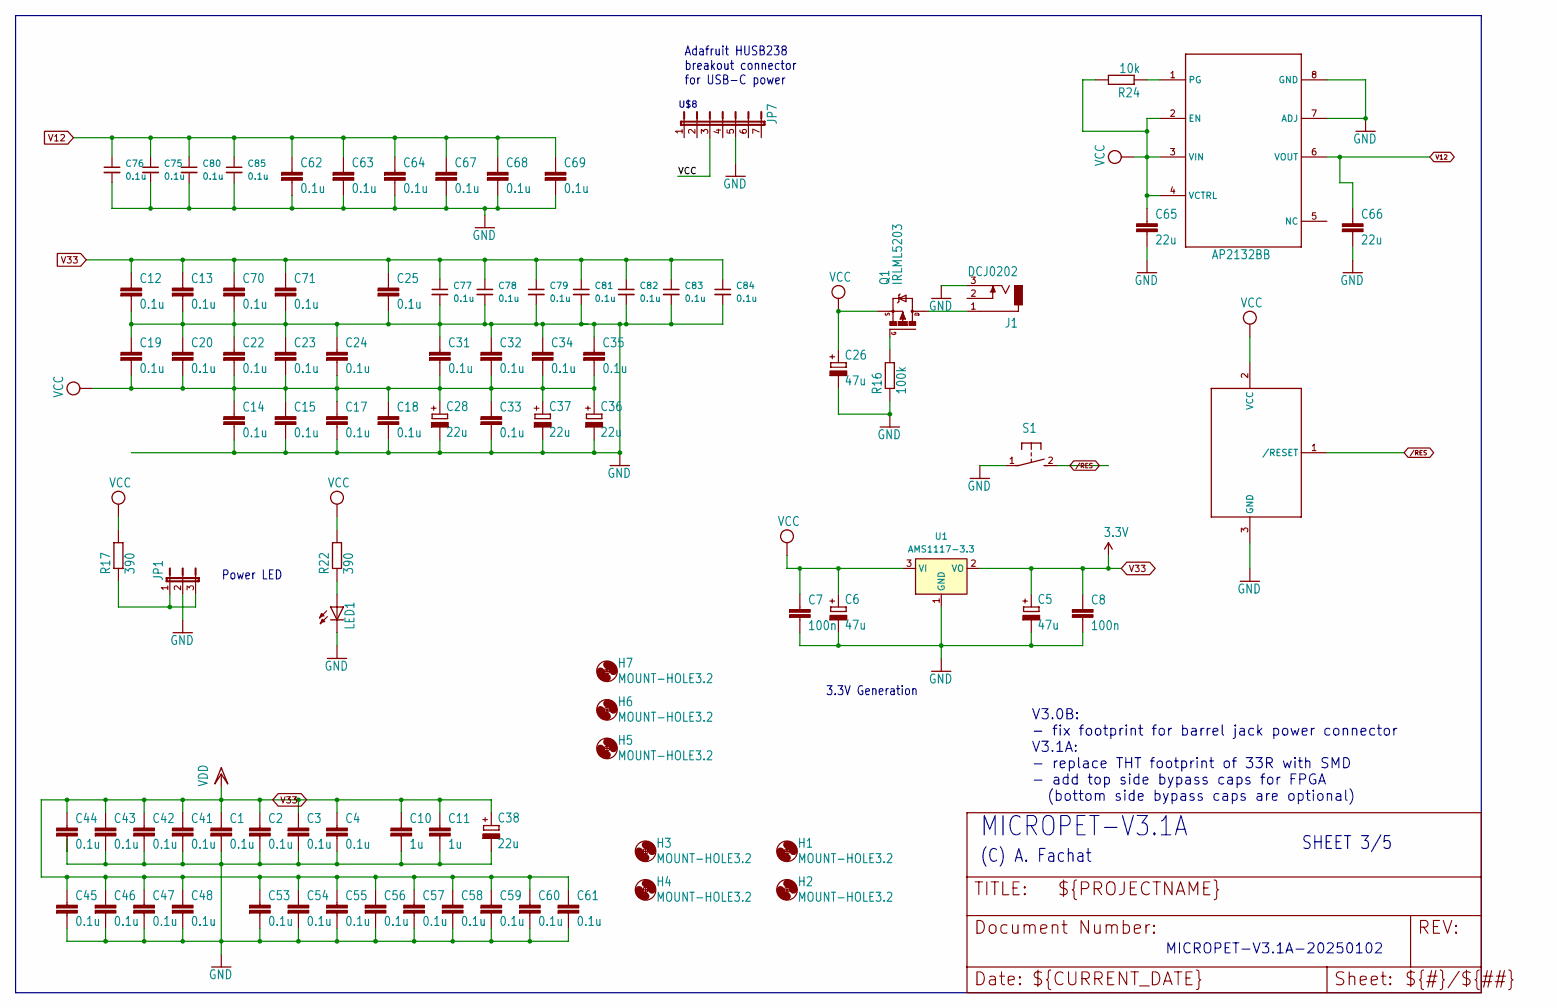
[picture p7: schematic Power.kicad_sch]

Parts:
C1, C2, C3, C4, C12, C13, C14, C15, C17, C18, C19, C20, C22, C23, C24, C25, C31, C32, C33, C34, C35, C41, C42, C43, C44, C45, C46, C47, C48, C53, C54, C55, C56, C57, C58, C59, C60, C61, C62, C63, C64, C67, C68, C69, C70, C71: 0.1u; C0603
C5: 47u; E5-8,5
C6: 47u; E5-6
C7, C8: 100n; C0603
C10, C11: 1u; C0603
C26: 47u; E2,5-6
C28, C36, C37, C38: 22u; E2,5-6
C65, C66: 22u; C0805
C75, C76, C77, C78, C79, C80, C81, C82, C83, C84, C85: 0.1u; C_0603_1608Metric
H1, H2, H3, H4, H5, H6, H7: MOUNT-HOLE3.2; 3,2
J1: DCJ0202
JP1: JP2E; JP2
LED1: LED3MM
Q1: IRLML5203; MICRO3
R16: 100k; 0207_2V
R17, R22: 390; 0207_2V
R24: 10k; R_0805_2012Metric_Pad1.20x1.40mm_HandSolder
S1: 31-XX; B3F-31XX
U1: AMS1117-3.3; SOT-223-3_TabPin2
U$3: DS1813; TO92
U$8: JP7; PinHeader_1x07_P2.54mm_Vertical
U$16: AP2132BB; PSOP-8-FIXED

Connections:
GND: C1.2, C2.2, C3.2, C4.2, C5.-, C6.-, C7.2, C8.2, C10.2, C11.2, C12.2, C13.2, C14.2, C15.2, C17.2, C18.2, C19.1, C20.1, C22.1, C23.1, C24.1, C25.2, C26.-, C28.-, C31.1, C32.1, C33.2, C34.1, C35.1, C36.-, C37.-, C38.-, C41.2, C42.2, C43.2, C44.2, C45.2, C46.2, C47.2, C48.2, C53.2, C54.2, C55.2, C56.2, C57.2, C58.2, C59.2, C60.2, C61.2, C62.2, C63.2, C64.2, C65.2, C66.2, C67.2, C68.2, C69.2, C70.2, C71.2, C75.2, C76.2, C77.2, C78.2, C79.2, C80.2, C81.2, C82.2, C83.2, C84.2, C85.2, J1.3, JP1.2, LED1.K (C), R16.1, S1.1, U1.1 (GND), U$3.3 (GND), U$8.5, U$16.7 (ADJ), U$16.8 (GND); also elsewhere on the board
unnamed: JP1.1, JP1.3, R17.1
unnamed: LED1.A, R22.1
unnamed: J1.1, Q1.3 (D)
unnamed: Q1.1 (G), R16.2
unnamed: R24.1, U$16.1 (PG)
V12: C62.1, C63.1, C64.1, C66.1, C67.1, C68.1, C69.1, C75.1, C76.1, C80.1, C85.1, U$16.6 (VOUT); also elsewhere on the board
V33: C1.1, C2.1, C3.1, C4.1, C5.+, C8.1, C10.1, C11.1, C12.1, C13.1, C25.1, C38.+, C41.1, C42.1, C43.1, C44.1, C45.1, C46.1, C47.1, C48.1, C53.1, C54.1, C55.1, C56.1, C57.1, C58.1, C59.1, C60.1, C61.1, C70.1, C71.1, C77.1, C78.1, C79.1, C81.1, C82.1, C83.1, C84.1, U1.2 (VO); also elsewhere on the board
VCC: C6.+, C7.1, C14.1, C15.1, C17.1, C18.1, C19.2, C20.2, C22.2, C23.2, C24.2, C26.+, C28.+, C31.2, C32.2, C33.1, C34.2, C35.2, C36.+, C37.+, C65.1, Q1.2 (S), R17.2, R22.2, R24.2, U1.3 (VI), U$3.2 (VCC), U$8.3, U$16.2 (EN), U$16.3 (VIN), U$16.4 (VCTRL); also elsewhere on the board

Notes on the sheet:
Adafruit HUSB238 breakout connector for USB-C power
(C) A. Fachat
U$8
SHEET 3/5
V3.0B: - fix footprint for barrel jack power connector V3.1A: - replace THT footprint of 33R with SMD - add top side bypass caps for FPGA (bottom side bypass caps are optional)
3.3V Generation
MICROPET-V3.1A
Power LED
MICROPET-V3.1A-20250102

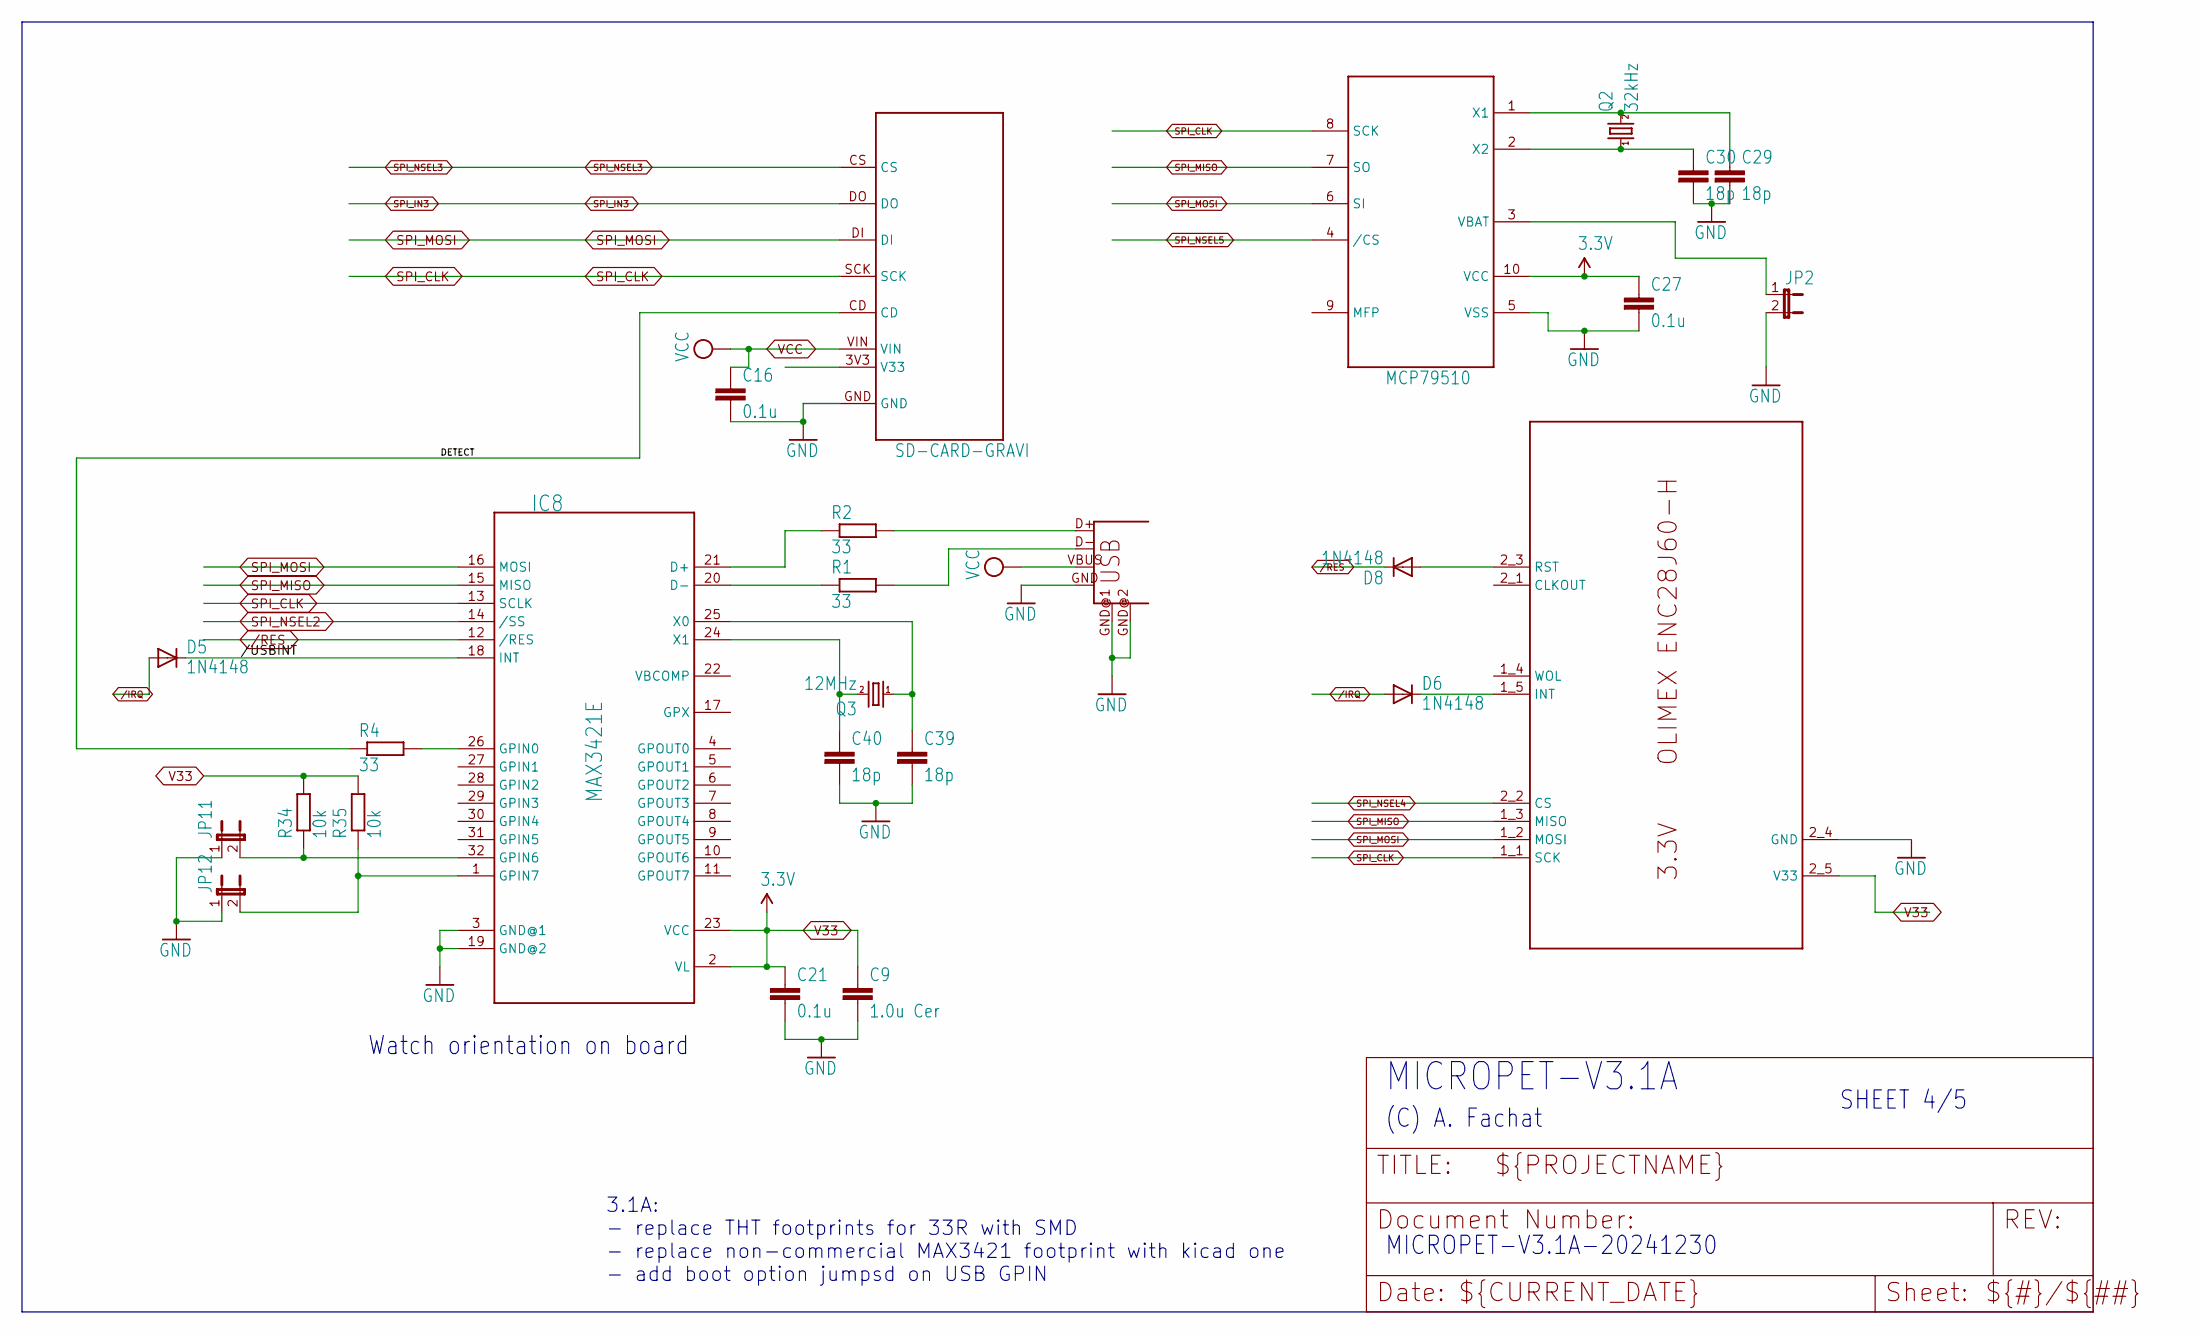
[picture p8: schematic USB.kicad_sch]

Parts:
C9: 1.0u Cer; C0603
C16, C21, C27: 0.1u; C0603
C29, C30, C39, C40: 18p; C0603
D5, D6, D8: 1N4148; D-5
IC8: MAX3421E; LQFP-32_5x5mm_P0.5mm
JP2, JP11, JP12: JP1E; JP1
Q2: 32kHz; TC26H
Q3: 12MHz; HC49_S
R1, R2, R4: 33; R_0805_2012Metric_Pad1.20x1.40mm_HandSolder
R34, R35: 10k; R_0805_2012Metric_Pad1.20x1.40mm_HandSolder
U$9: ETHOLIENC
U$12: SD-CARD-GRAVI; GRAVITECH-SDCARD
U$13: MCP79510; MSOP10
USB1: USB-A-H

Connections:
/USB/DETECT: R4.1, U$12.CD
/USB//USBINT: D5.C, IC8.18 (INT)
GND: C9.2, C16.2, C21.2, C27.2, C29.2, C30.2, C39.2, C40.2, IC8.3 (GND@1), IC8.19 (GND@2), JP2.2, JP11.1, JP12.1, U$9.2_4 (GND), U$12.GND, U$13.5 (VSS), USB1.GND, USB1.GND@1, USB1.GND@2; also elsewhere on the board
unnamed: IC8.21 (D+), R2.1
unnamed: IC8.20 (D-), R1.1
unnamed: IC8.26 (GPIN0), R4.2
unnamed: IC8.32 (GPIN6), JP11.2, R34.1
unnamed: IC8.1 (GPIN7), JP12.2, R35.1
unnamed: C39.1, IC8.25 (X0), Q3.1
unnamed: C40.1, IC8.24 (X1), Q3.2
unnamed: R1.2, USB1.D-
unnamed: R2.2, USB1.D+
unnamed: D6.C, U$9.1_5 (INT)
unnamed: D8.A, U$9.2_3 (RST)
unnamed: JP2.1, U$13.3 (VBAT)
unnamed: C29.1, Q2.2, U$13.1 (X1)
unnamed: C30.1, Q2.1, U$13.2 (X2)
SPI_CLK: IC8.13 (SCLK), U$9.1_1 (SCK), U$12.SCK, U$13.8 (SCK); also elsewhere on the board
SPI_IN3: U$12.DO; also elsewhere on the board
SPI_MISO: IC8.15 (MISO), U$9.1_3 (MISO), U$13.7 (SO); also elsewhere on the board
SPI_MOSI: IC8.16 (MOSI), U$9.1_2 (MOSI), U$12.DI, U$13.6 (SI); also elsewhere on the board
SPI_NSEL2: IC8.14 (/SS); also elsewhere on the board
SPI_NSEL3: U$12.CS; also elsewhere on the board
SPI_NSEL4: U$9.2_2 (CS); also elsewhere on the board
SPI_NSEL5: U$13.4 (/CS); also elsewhere on the board
V33: C9.1, C21.1, C27.1, IC8.2 (VL), IC8.23 (VCC), R34.2, R35.2, U$9.2_5 (V33), U$13.10 (VCC); also elsewhere on the board
VCC: C16.1, U$12.VIN, USB1.VBUS; also elsewhere on the board
/IRQ: D5.A, D6.A; also elsewhere on the board

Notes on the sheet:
MICROPET-V3.1A-20241230
(C) A. Fachat
Watch orientation on board~{}
MICROPET-V3.1A
3.1A: - replace THT footprints for 33R with SMD - replace non-commercial MAX3421 footprint with kicad one - add boot option jumpsd on USB GPIN
SHEET 4/5

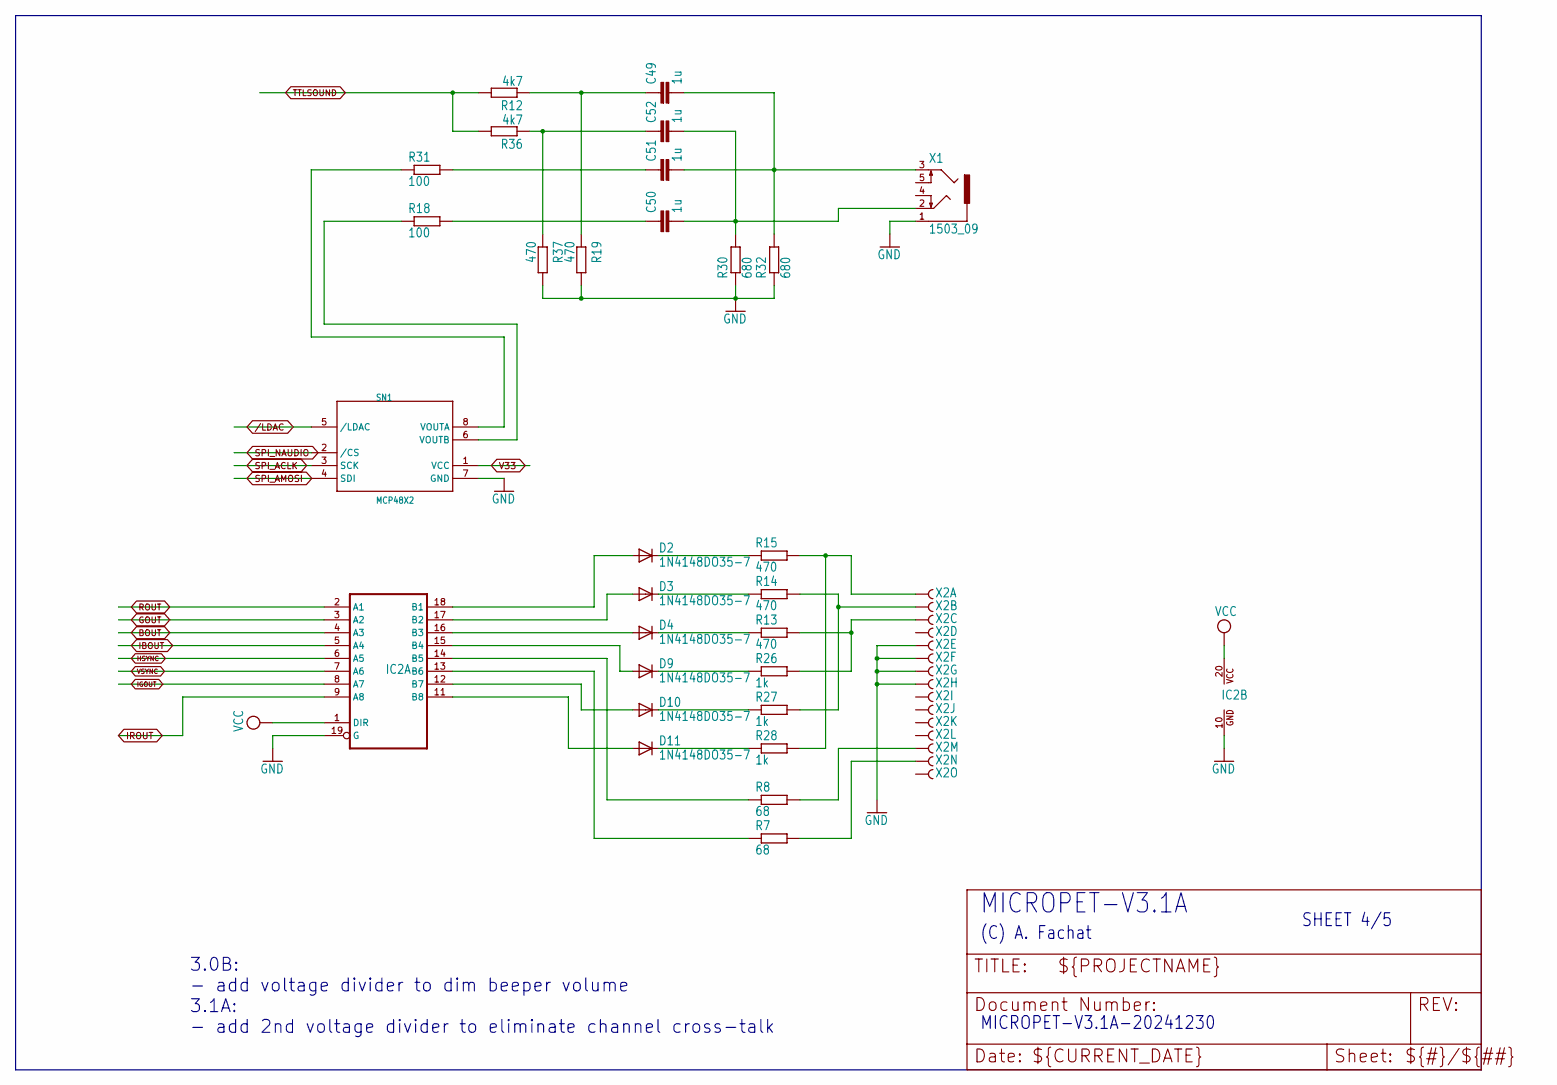
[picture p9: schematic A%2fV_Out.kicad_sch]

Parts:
C49, C50, C51, C52: 1u; C050-025X075
D2, D3, D4, D9, D10, D11: 1N4148DO35-7; DO35-7
IC2: 74245DW; SO20W
R7, R8: 68; 0204V
R12, R36: 4k7; 0204V
R13, R14, R15, R19, R37: 470; 0204V
R18, R31: 100; 0204V
R26, R27, R28: 1k; 0204V
R30, R32: 680; 0204V
SN1: MCP48X2; SOIC8
X1: 1503_09
X2: D-SUB15-HDR15RA; HDR15RA

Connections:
BOUT: IC2.4 (A3); also elsewhere on the board
GND: IC2.10 (GND), IC2.19 (G), R19.2, R30.1, R32.1, R37.2, SN1.7 (GND), X1.1, X2.5 (F), X2.6 (F), X2.7 (F), X2.8 (F); also elsewhere on the board
GOUT: IC2.3 (A2); also elsewhere on the board
HSYNC: IC2.6 (A5); also elsewhere on the board
IBOUT: IC2.5 (A4); also elsewhere on the board
IGOUT: IC2.8 (A7); also elsewhere on the board
IROUT: IC2.9 (A8); also elsewhere on the board
unnamed: C49.1, R12.1, R19.1
unnamed: C49.2, C51.2, R32.2, X1.3
unnamed: C50.1, R18.2
unnamed: C50.2, C52.2, R30.2, X1.2
unnamed: C51.1, R31.2
unnamed: C52.1, R36.1, R37.1
unnamed: D2.C, R15.1
unnamed: D3.C, R14.1
unnamed: D4.C, R13.1
unnamed: D9.C, R26.1
unnamed: D10.C, R27.1
unnamed: D11.C, R28.1
unnamed: D2.A, IC2.18 (B1)
unnamed: D3.A, IC2.17 (B2)
unnamed: D4.A, IC2.16 (B3)
unnamed: D9.A, IC2.15 (B4)
unnamed: IC2.14 (B5), R8.1
unnamed: IC2.13 (B6), R7.1
unnamed: D10.A, IC2.12 (B7)
unnamed: D11.A, IC2.11 (B8)
unnamed: R31.1, SN1.8 (VOUTA)
unnamed: R18.1, SN1.6 (VOUTB)
unnamed: R15.2, R28.2, X2.1 (F)
unnamed: R14.2, R27.2, X2.2 (F)
unnamed: R13.2, R26.2, X2.3 (F)
unnamed: R8.2, X2.13 (F)
unnamed: R7.2, X2.14 (F)
ROUT: IC2.2 (A1); also elsewhere on the board
SPI_ACLK: SN1.3 (SCK); also elsewhere on the board
SPI_AMOSI: SN1.4 (SDI); also elsewhere on the board
SPI_NAUDIO: SN1.2 (/CS); also elsewhere on the board
TTLSOUND: R12.2, R36.2; also elsewhere on the board
V33: SN1.1 (VCC); also elsewhere on the board
VCC: IC2.1 (DIR), IC2.20 (VCC); also elsewhere on the board
VSYNC: IC2.7 (A6); also elsewhere on the board
/LDAC: SN1.5 (/LDAC); also elsewhere on the board

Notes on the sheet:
3.0B: - add voltage divider to dim beeper volume 3.1A: - add 2nd voltage divider to eliminate channel cross-talk
MICROPET-V3.1A
MICROPET-V3.1A-20241230
SHEET 4/5
(C) A. Fachat

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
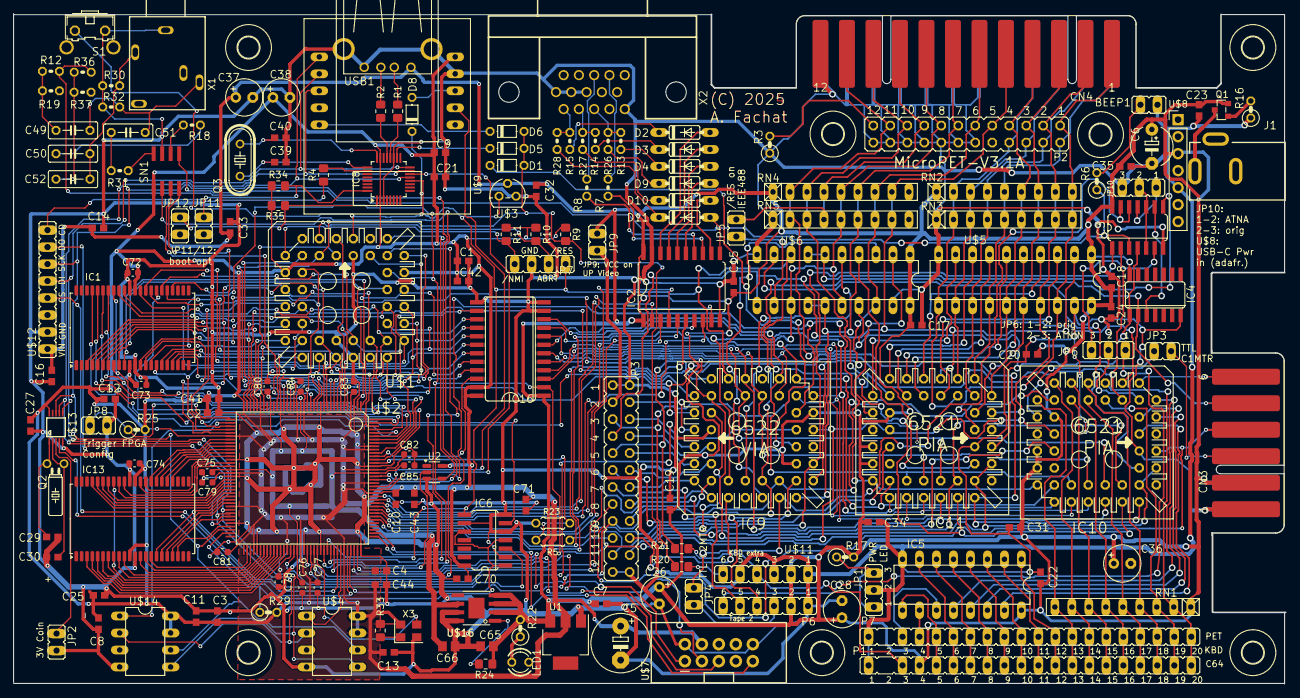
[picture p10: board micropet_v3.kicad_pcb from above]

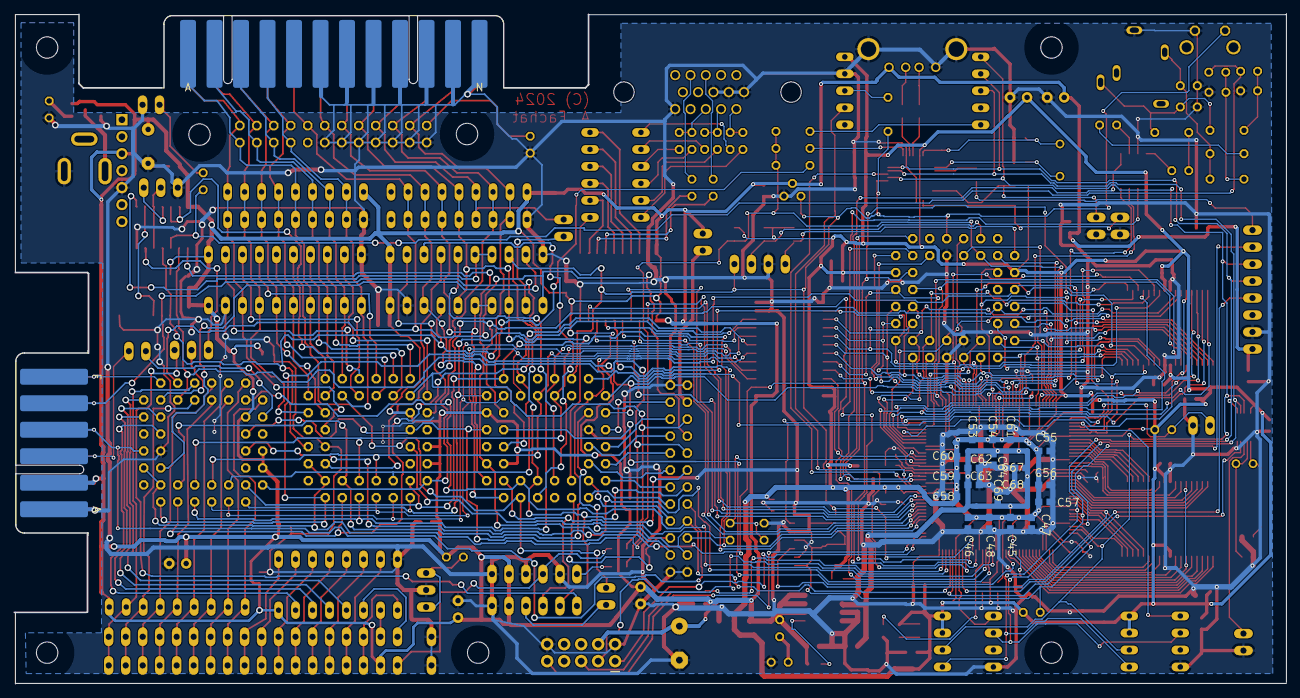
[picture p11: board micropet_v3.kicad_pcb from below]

Board: 2 copper layers, 190.2 x 100.3 mm, 203 parts (19 on the bottom side), 253 nets.

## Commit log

2024-06-18 update to MicroPET 3.0b
    [A%2fV_Out.kicad_sch, BUS%2fVoltageconv.kicad_sch, CPU,RAM,ROM.kicad_sch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]
2024-06-18 update to 3.0b, corrected gerbers
    [bom.csv, designators.csv, positions.csv]
2024-09-12 add mouser bom, fixes #3
    [micropet_v3.0a-BOM.xlsx]
2024-12-31 working on r3.1a
    [A%2fV_Out.kicad_sch, BUS%2fVoltageconv.kicad_sch, CPU,RAM,ROM.kicad_sch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]
2025-01-02 draft final layout mupet 3.1a
    [CPU,RAM,ROM.kicad_sch, Power.kicad_sch, USB.kicad_sch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]
2025-01-23 adapt audio output caps
    [A%2fV_Out.kicad_sch, BUS%2fVoltageconv.kicad_sch, CPU,RAM,ROM.kicad_sch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]

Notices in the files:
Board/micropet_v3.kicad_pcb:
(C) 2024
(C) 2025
